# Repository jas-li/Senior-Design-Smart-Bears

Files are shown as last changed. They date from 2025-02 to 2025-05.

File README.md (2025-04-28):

# Senior-Design-Smart-Bears

### Team 29 - Smart Bears
Shamir Legaspi\
David Li\
Jason Li\
Lukas Chin\
Jake Lee

## Smart System for the Visually Impaired

Smart_System

## Objective

The goal of the Smart System for Visually Impaired is to improve its users’ abilities to navigate safely. 

The first way it achieves this goal is by providing users with more visual context about their surroundings through other mediums. Visual context is transformed into text descriptions in audio and semantic haptic feedback. 

A binary assessment of whether the current surroundings are navigationally safe or unsafe is quickly transmitted to the user through haptic feedback. This way, users can quickly make a decision to not proceed before knowing the full description of their surroundings which would take much longer to propagate than a simple buzzing signal. 

The system also illuminates the user’s wrist in dark light conditions. Though this does not directly help the user navigate, it helps others navigate around the user. 

In its current state, the system achieves all of these goals, but its performance in terms of latency, accuracy, and over helpfulness can always be improved. Each aspect of the system comes with a few things to keep in mind while developing them.

## Overview
* Stereo vision-based depth mapping and object recognition
* Real-time haptic (vibration) and auditory (speech) feedback
* One-button user interface on wrist-wearable
* Intelligent visibility system (LEDs for low-light)
* Wireless connectivity (WiFi and Bluetooth)
* Designed for expandability and compliance with accessibility and safety standards

## Quick Start

### Hardware Setup
1. Mount Cameras:
Attach the dual USB stereo cameras to the Smart Cap and connect to the Raspberry Pi’s USB ports.

2. Raspberry Pi:
Place the Raspberry Pi 5 in a weather-protected case. Power it with a 5V portable battery.

3. Wrist-Wearable:
Secure the wrist module to the user’s wrist, ensuring the photoresistor is unobstructed and the button is accessible.

4. Networking:
Connect both the ESP32 (in the wrist-wearable) and the Raspberry Pi to the same WiFi network.

5. Audio Output:
Pair the bone conduction headset to the Raspberry Pi via Bluetooth.

### Software Setup
1. Access Raspberry Pi:
SSH into the Pi or use a monitor and keyboard.

2. Project Directory:
Navigate to the project root directory.

3. Run Main Script:
Execute pi.py to start the main pipeline (waits for wrist-wearable trigger, handles image capture, depth mapping, LLM query, and feedback).

4. ESP32 Firmware:
Ensure the ESP32 is flashed with the provided firmware and has open UDP ports.
Run esp.py to handle communication for the buzzer and LEDs.

5. System Test:
Press the wrist-wearable button to initiate a query.
Confirm system activation by checking for audio (speech) and haptic (vibration) feedback.
### Operation
* Normal Use:
The user points their head, presses the wrist button, and receives a spoken description of the environment plus haptic alerts for nearby obstacles. LEDs activate in low-light conditions.
* Troubleshooting:
If feedback is missing, check WiFi/Bluetooth connections.
Restart ESP32 or Raspberry Pi if communication is lost.
For persistent issues, review setup logs and ensure all scripts are running.
### System Architecture
* Smart Cap:
Dual 2MP USB cameras, Raspberry Pi 5 (16GB RAM), portable battery, wireless connectivity.
* Wrist-Wearable:
ESP32 microcontroller, vibration motor, button, LEDs, photoresistor, adjustable strap.
* Audio Output:
Bone conduction Bluetooth headset.
* Communication:
UDP over WiFi (ESP32 ↔ Raspberry Pi)
Bluetooth audio (Raspberry Pi ↔ headset)

## Network
- We are currently using a router to connect to the Raspberry Pi 5 and the TinyPICO ESP 32.
  - SSID: `smartbears`
  - Password: ` `

## Raspberry Pi

We utilized a combiantion of SSH + RealVNC Viewer for faster development. To do so connect to the Pi at `192.168.1.141`
- user: `pi`
- password: `smartbears`

### Bluetooth

We have set up a bluetooth device to enable speaker output to the wireless headset.

To set up bluetooth with the Raspberry Pi, run `sudo bluetoothctl` to start the bluetooth control tool.

Find your device and its respective address. Then, pair and trust the bluetooth device:

```
pair 41:42:D4:02:07:00
trust 41:42:D4:02:07:00
```

You can now exit bluetoothctl with `exit`. You only need to do this once.

Run this command any time you want to reconnect the headset:
```
bluetoothctl connect 41:42:D4:02:07:00
```

## Final Hardware Diagram
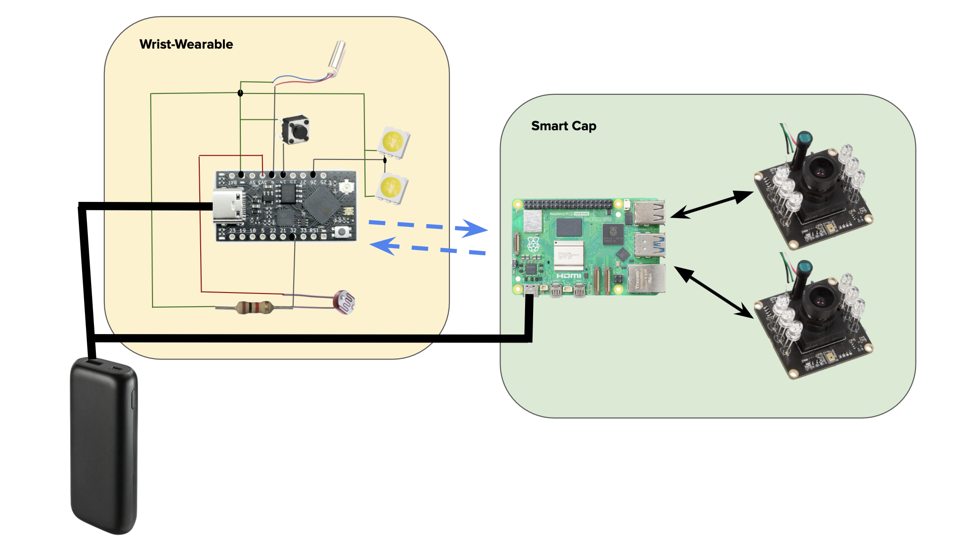
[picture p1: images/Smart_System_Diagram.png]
Smart System Diagram


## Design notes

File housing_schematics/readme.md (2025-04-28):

# CAD Files

CAD files used for designing the Smart System are located here.

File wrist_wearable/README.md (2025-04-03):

# Wrist-Wearable

MAC Address: D4:D4:DA:AA:31:E6

GPIO Pins Used
* LED 26
* Buzzer 4
* Button 14
* 32 Photoresistor

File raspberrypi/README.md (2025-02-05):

# Raspberry Pi Zero

### Router

**Plug the router into LAN2**

After turning on the router, the Raspberry Pi Zero should connect to the `smartbears` SSID. This may take 5-10 minutes. 

To check all devices on the network, connect to the wifi on your device, and go to the following link: http://192.168.1.1/status-devices.asp

### SSH

To ssh into the Raspberry Pi Zero:

```
ssh pi@192.168.1.142
```

You may get this error:

```
@@@@@@@@@@@@@@@@@@@@@@@@@@@@@@@@@@@@@@@@@@@@@@@@@@@@@@@@@@@
@    WARNING: REMOTE HOST IDENTIFICATION HAS CHANGED!     @
@@@@@@@@@@@@@@@@@@@@@@@@@@@@@@@@@@@@@@@@@@@@@@@@@@@@@@@@@@@
IT IS POSSIBLE THAT SOMEONE IS DOING SOMETHING NASTY!
Someone could be eavesdropping on you right now (man-in-the-middle attack)!
It is also possible that a host key has just been changed.
```

If so, try running:

```
ssh-keygen -R 192.168.1.142
```

Then, try to ssh into the pi again.

### PiCam

After running `picam.py`, you should be able to see the live feed from the PiCam at: http://192.168.1.142:5000/video_feed

### Video Stream Communcation 

Run `camera_stream_client` on the raspberry Pi

Run `camera_stream_server` on your computer

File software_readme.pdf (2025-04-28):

## Software Report

### smart_cap/stereoscopic/capture_calibration.py

This module handles capturing images for calibrating the stereoscopic camera setup. The only necessary inputs for this module are the camera feeds from both cameras. It is set up to work with two 1920 by 1080 USB cameras. Based on how the cameras are plugged in, they will be mapped to device number 2 for the left camera and device number 0 for the right camera. These parameters are the only things that should be subject to change if the cameras and their connection scheme are changed. The module saves the captured images to directories called left and right. When capturing calibration images for a new stereo camera setup, it is necessary to empty the contents of output directories first. It may be helpful to empty the output directories even when using the same camera set up in the event that an undesirable calibration error is obtained. It can also be useful to capture additional images without overwriting those in the output directories. This can be done by changing the image_count variable to a number higher than the greatest number in the output directory. To operate the script, both cameras must be plugged in. When the script is running, it will show a live feed of the camera outputs. To generate the calibration images, all one needs to do is place the calibration reference image in the frames of both cameras and press c to capture images. When a sufficient number of images are captured, q can be pressed to quit out of the script.

### smart_cap/stereoscopic/calibration.py

This module performs stereoscopic camera calibration given a calibration data set of images captured of a 10 by 7 checkerboard pattern of 25 millimeter squares. It then performs stereoscopic calibration by identifying the checkerboard pattern in each pair of images from the left and right cameras and finding the disparities between common points. This is then saved to a file called stereo_calibration.npz which can be renamed and referenced in the future.

### smart_cap/pi.py

This module runs all the code needed for our Raspberry Pi. It first opens up a UDP server to allow for communication with the ESP32. It then starts initialization of the cameras, text-to-speech module, and our cloud-based LLM. The camera initialization includes the calibration matrix obtained from the calibration modules. For our LLM initialization, we created a prompt to feed our LLM. Next, the code waits for a response from the UDP server, which will be a button press from the wrist-wearable. This will start up the whole Raspberry Pi process, which includes capturing an image using the two cameras, mapping it with conversion based on the calibration settings, and running the Gemini LLM. Our LLM inputs include the calibrated images and API key, and our output is text response, as well as a boolean ‘SAFE’ or UNSAFE’.

This boolean is sent to the ESP32 through the UDP server, and the text response is sent to the headset’s speakers through a text-to-speech module.

### wrist_wearable/esp.py

This module implements all core functionality for a wrist-wearable device using an ESP32 microcontroller. It establishes a WiFi connection to a specified network and communicates with a UDP server to send and receive real-time messages. The device continuously monitors ambient light using a photoresistor, dynamically adjusting the brightness of an onboard LED with a smooth, sine-wave gradient when low light conditions are detected. This ensures the device remains visible and responsive to changes in the surrounding environment.
User interaction is facilitated through a physical button. When the button is pressed, the module sends a notification to the server and awaits a response. Depending on the server’s reply, the device activates a vibration motor to provide haptic feedback: a single pulse for standard acknowledgments or a series of strong pulses for unsafe or emergency alerts. The ESP grabs either a ‘SAFE’ or ‘UNSAFE’ input from the Raspberry Pi which determines the vibration motor’s strength. The module is designed with efficient state management to avoid repeated signals and ensures all subsystems-light sensing, button detection, vibration feedback, and network communication-operate concurrently and responsively within the main loop. This makes the module suitable for applications where immediate feedback and environmental awareness are critical, such as personal safety or alert systems.

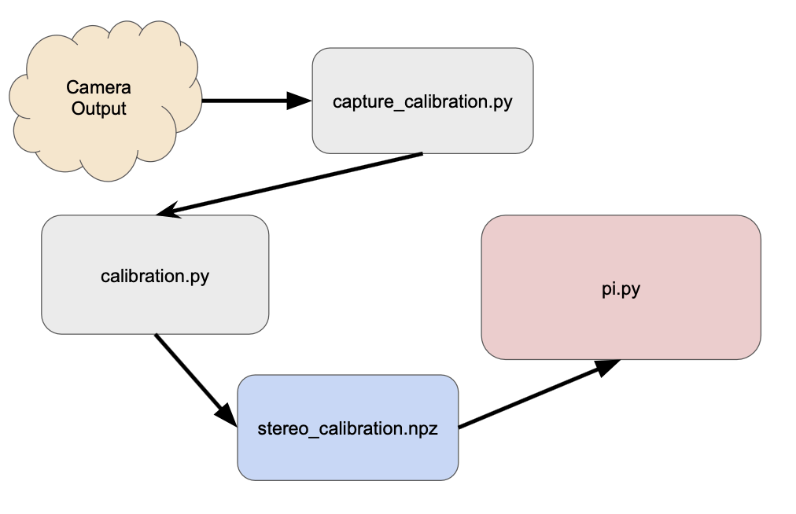
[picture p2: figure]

Flow chart indicating dependencies between functions, programs, and hardware outputs. Initially the cameras output multiple photographs that are used for calibration. capture_calibration.py handles all of the photographs that are taken and organizes them into two separate buckets, one for the left camera and one for the right camera. For optimal calibration, we recommend taking 20 photos on each camera; the capture_calibration.py script handles capturing photos for both cameras at the same time. Be sure to hold still when taking photos as there is a small delay in between taking the left and right camera photo. Photos taken with the capture_calibration.py should be of chessboard black and white patterns. See image below for reference. The chessboard image can be printed or displayed using a tablet. Multiple angles of the chessboard should be taken.

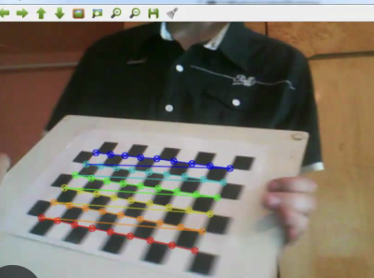
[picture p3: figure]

Once all of the photos are taken, calibration.py will then begin by detecting chessboard patterns in the image pairs. The script uses OpenCV’s findChessboardCorners to refine the black and white intersections in both left and right camera images. For each successful detection, it refines the corner coordinates with sub-pixel accuracy using cornerSubPix, then it stores the 3D object points (real-world chessboard coordinates) and 2D image points from both cameras. Individual camera calibration follows, where calibrateCamera calculates each camera’s intrinsic parameters:
- Camera matrix (focal length and optical center)
- Distortion coefficients (radial and tangential distortion)
- RMS reprojection error (lower values and indicate better calibration) The stereo calibration phase (stereoCalibrate) then determines the spatial relationship between cameras by solving for:
- Rotation matrix (R) and translation vector (T) between cameras
- Essential matrix and fundamental matrix for epipolar geometry
- Refined camera matrices accounting for stereo alignment
Finally, all calibration parameters get saved to stereo_calibration.npz for use in downstream applications like depth mapping. The script outputs RMS errors at each stage, with typical successful calibrations achieving errors below 0.5 pixels.

### Dev/Build Tool Information

The Raspberry Pi is running Python 3.11.2. No other build tools or languages are used. The core libraries and their versions are as follows.

google-genai==1.9.0
Pillow==9.4.0
opencv-python==4.11.0.86
pyttsx3==2.98
numpy==1.24.2
python-dotenv==0.21.0

The TinyPICO ESP32 is running MicroPython v1.24.1. Only libraries from the standard library are used, and no other build tools or languages are used.

### Installation Guide

The TinyPICO ESP32 comes with the appropriate MicroPython version installed. Since no other libraries are required, the project can be considered fully installed and functional once the GitHub repository is cloned. If another MicroPython-compatible device were to be used in future iterations instead of the TinyPICO ESP32, then that would be the only other dependency that would need to be installed. This can be done easily using Thonny IDE.
The Raspberry Pi does not have many dependencies to install. First, you must install Python 3.11.2. With Python installed, a developer can create a virtual environment and install the dependencies by running the following: pip install -r requirements.txt. Lastly, a .env file must be created with the contents GOOGLE_API_KEY=..., replacing the ellipses with the actual contents of a valid Google AI Studio API key. API keys can be generated from Google Studio at the following link: https://aistudio.google.com/app/apikey. The rate limits for free users are generous enough to serve developers.

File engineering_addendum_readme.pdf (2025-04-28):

## Engineering Addendum

### Goals and Progress

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

### Stereoscopic Setup

The stereo vision system is the backbone of this project. At times, getting both cameras to work simultaneously can be tricky. This task poses both software and hardware challenges. During development, cameras are often put in more vulnerable positions considering that housing may be improved or the cameras themselves are being swapped in and out. Because of this, it is important to always verify that the hardware is working, before trying to solve any potential software issues. Cameras can be verified individually, by plugging in one at a time and capturing an image. When connecting or removing devices from the Raspberry Pi, always make sure to power the Raspberry Pi off first. This prevents any potential damage to the devices. Once the cameras are verified to be working, it is also important to verify that the connection ports are working. These can be verified by plugging in a known working camera into an unverified port and taking a picture. Once the cameras and ports are verified, any issues with the stereoscopic setup can be attributed to software.
Another potential problem that may arise when working with the stereoscopic setup is the device numbers used to reference the cameras. On many setups like with a laptop, when two cameras are plugged in, they can be referenced through device numbers 0 and 1. However, in our experience with the Raspberry Pi, the device numbers were not always consecutive and in order, leading us to use reference numbers 0 and 2. These references are determined by the underlying operating system, so even if a different library is used to interact with the cameras, this referencing guide will remain relevant. An example of establishing the video capture references to the cameras can be found below.

# Example of initializing video captures

cap_left = cv2.VideoCapture(0) # Adjust index if needed cap_right = cv2.VideoCapture(2) # Adjust index if needed

### Stereoscopic Calibration

When iterating on the camera selection or the mounting system, it is important to always calibrate the cameras and their stereoscopic setup. Optimizing the calibration error is pivotal for ensuring that the depth mapping output is accurate and useful. Our calibration scripts use a checkerboard pattern with 10 by 7 internal corners as the reference calibration image. Each of the squares of the checkerboard When using the calibration scripts, make sure to only settle for a calibration error below 1 pixel. Ideally, the mean error should be below .5 pixels. Any higher mean error will not yield a helpful result. To improve this calibration error, make sure to take the calibration images in well-lit conditions. It is important to also have the calibration reference image fully in frame and in multiple different angles across all of the captured calibration images.

### Depth Mapping

Even after performing calibration, there are many parameters to tune that can affect the quality and usability of the depth map. The main things we modified when working with OpenCV’s stereo block matching algorithm for depth mapping were the parameters for the number of disparities and the block size. Other features we modified were the speckle window size, speckle range, and texture threshold. The reason we modified these aspects was to find a balance between making the depth mapping sensitive enough for low texture objects without having a large, distracting amount of noise.

### Working on the ESP32

The ESP32 deals with many hard coded constants. These range from WiFi credentials and the IP of the Raspberry Pi to the GPIO pins and parameters involved with sensors and output. When iterating on the ESP32 code, it is important to ensure that the constants used in the code reflect what is mapped out in the hardware. It is important to make use of the TinyPICO pin map for this. Ensuring that devices that require PWM or ADC are plugged into the appropriate ports is pivotal to the success of the project. Though the code handled by the ESP32 and the wrist wearable is not required to be concurrent, it would be best to avoid long sequential blocks of code that would prevent other functions from updating, when iterating on the functionality of the wrist wearable.

### Prompt Engineering

Though it is good to save on tokens when using LLMs, we found that including more tokens in the prompt can be beneficial in many cases. A longer prompt that does not increase the requirements of the output can improve the specificity of the train of thought of the LLM and its concision. Often, the bulk of the latency when interacting with an LLM comes from the LLM producing its output. By reducing the length of the output by having specific constraints in the prompt, latency can be reduced. Especially since we are passing images to the LLM alongside the text, the extra tokens in the text portion of the prompt are well worth the savings on output tokens.

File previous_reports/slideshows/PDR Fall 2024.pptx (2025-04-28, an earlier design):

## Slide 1

Smart System for Visually Impaired

Smart System for Visually Impaired

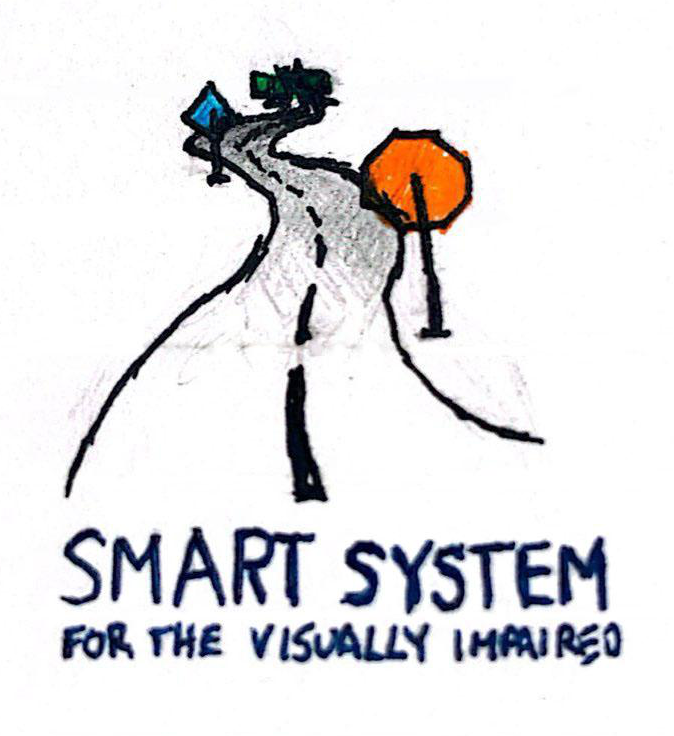
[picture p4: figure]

Lukas Chin, Jake Lee, Shamir Legaspi, David Li, Jason Li

## Introduction

## Introduction

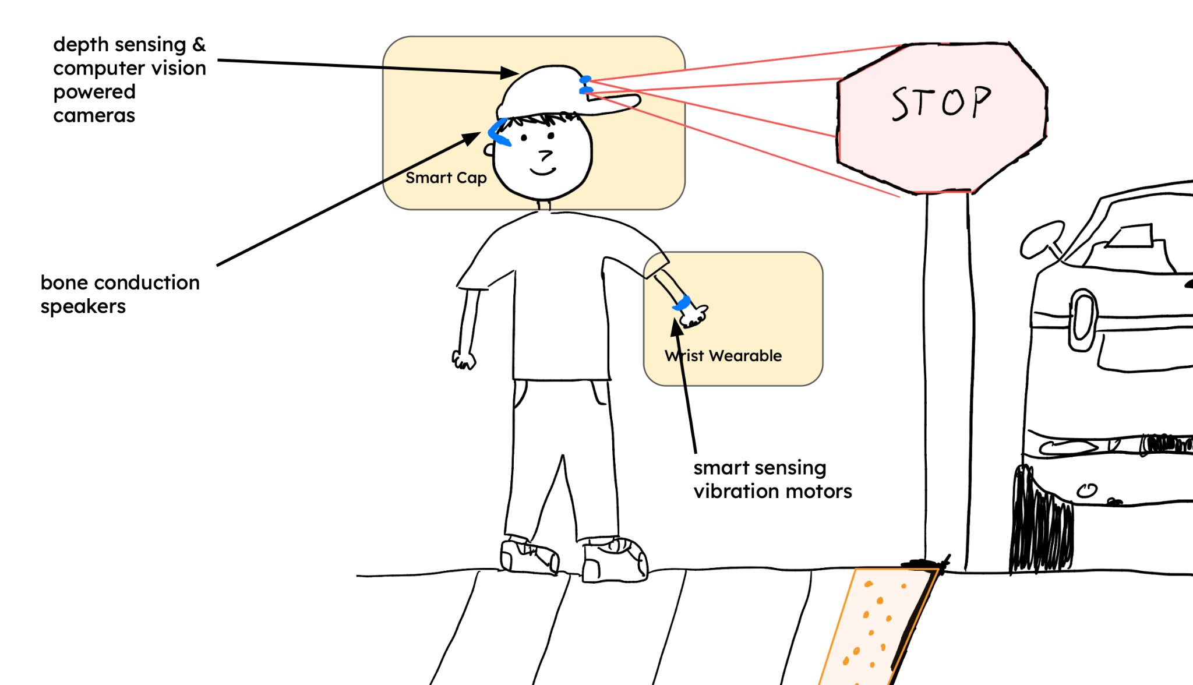
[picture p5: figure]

## Problem Statement

## Problem Statement

• Visually impaired individuals benefit from navigational assistance.
• White canes and guide dogs have significant limitations.
• Current solutions inadequately translate environmental information.
• Society requires accessible solutions.

## Requirements

## Requirements/Deliverables

Required Functions
• Transmit haptic signals through vibration motors
• Stream and process video inputs
• Text-to-speech output
• Real-time feedback (<1s)
• Lightweight and comfortable for extended wear (<1lb)
• Battery life: 12+ hours per charge
• Easy to use with minimal training required
• Multi-environment operation (<10% accuracy difference between different environments e.g. indoors and outdoors)

Deliverables
• Wrist wearable that transmits differentiable haptic signals based on surroundings.
• Smart cap that gives an audio description of surroundings based on objects detected, object distances, and user queries.

## Block Diagram

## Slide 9

Smart System for Visually Impaired

Smart Cap

Raspberry Pi 5

Raspberry Pi Camera Module

Raspberry Pi Camera Module

Microphone

Human speech input

Feeding live video stream

Depth Map Processing

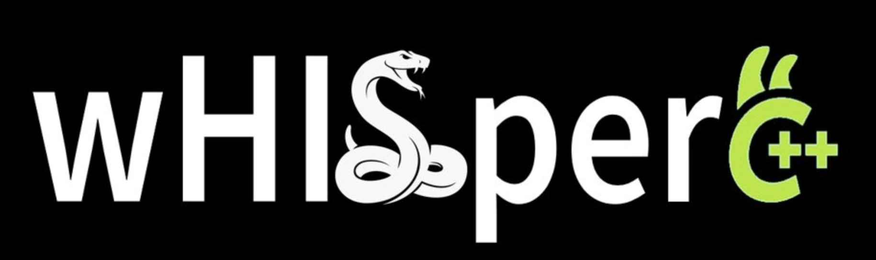
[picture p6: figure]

Bone conduction speakers

Object Inquiry Assistant

Text-to-Speech

Wrist Wearable

ESP32 Microcontroller

Intelligent Visibility System

Photoresistor

Light Emitting Diode Array

Variable Vibration Motors

## Technology/Design

## Object Detection

Object Detection Model: Implemented YOLOv3, pre-trained on the COCO dataset, via the OpenCV library to recognize common objects.
Hardware Setup: Utilized a Raspberry Pi Zero W with a Pi Camera Module to capture video streams, transmitted to an OpenCV server over a TCP connection for processing.
System Functionality: The server performs object detection on the video stream and integrates a text-to-speech library (pyttsx3) to announce identified objects in the frame.

## Depth Mapping and Distance Calculation

- Utilizing 2 Raspberry Pi camera modules, the Smart Cap can accurate sense depth of field.
- Depth Mapping can be to calculate distance of nearby and far obstacles for everyday walking.
- Smart Cap can provide haptic feedback even more reliably to the user with 2 Raspberry Pi camera inputs versus 1 camera (no depth mapping).

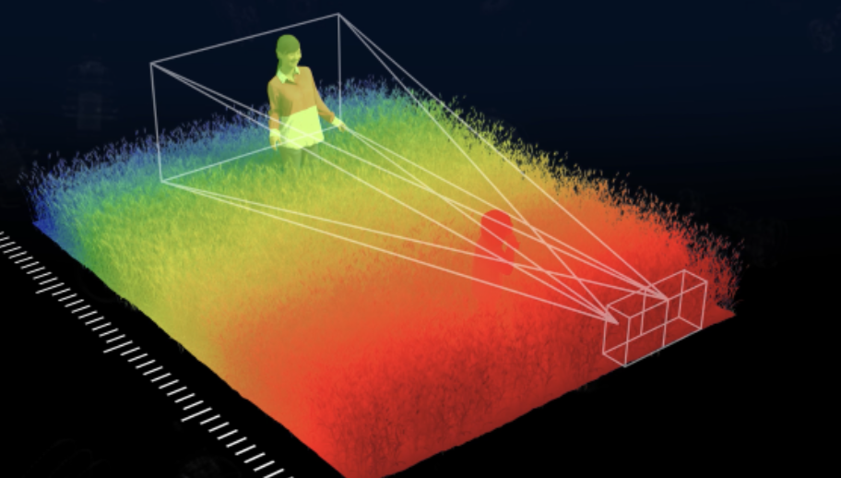
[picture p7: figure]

## Whisper.cpp

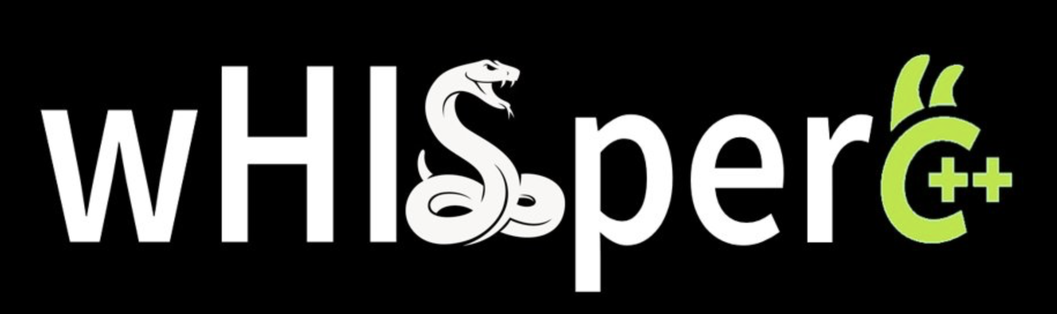
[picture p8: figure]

- Through a microphone on the Smart Cap, users can record a query that is processed into a format consumable by Whisper.cpp.
- The Smart Cap can then run the Whisper.cpp process with the audio of the recorded query as input to output text.
- Through this speech-to-text system, users will be able to speak to make queries that are turned into text that modifies the output of the Object Inquiry Assistant.

## Object Inquiry Assistant

Inputs:
- Depth map processing and OpenCV information from Pi Camera live-stream
- User speech-to-text from microphone using whisper.cpp
Outputs:
- Text-to-speech into bone conduction speakers
- Vibration motors on the wrist wearable

## Wrist Wearable

Inputs:
- Wireless data stream from Smart Cap visual feedback
- Outdoor illumination detection from photoresistor
Outputs:
- Variable vibration motors for haptic feedback and user notification
- High-visibility LED for user safety and convenience

## Prototype Results

## Prototype Results

Tasks | Successful? (Y/N)
Raspberry Pi and TinyPico are connected to router’s network | Y
Raspberry Pi’s camera module’s live stream can be observed on user’s computer | Y
TinyPico successfully sends request and receives responses | Y
TinyPico’s received responses trigger “notifications” which prompt vibration motors to turn on | Y
Computer vision Python script through user’s computer’s webcam successfully detects objects and reports accuracy of detection | Y
Able to communicate audibly to the user the detected objects | Y
User is able to sense a vibration when a target object is in frame | Y
User feedback in under 1 second | N

## Schedule

## Gantt Chart

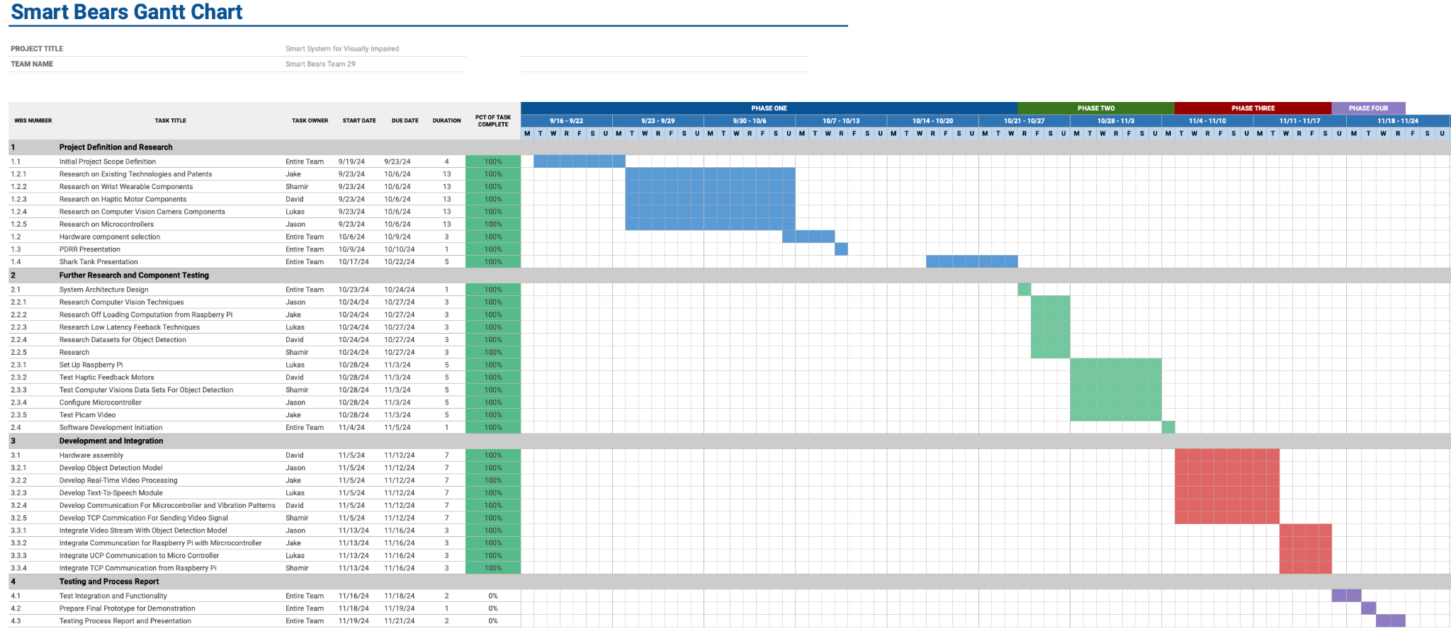
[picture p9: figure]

## What’s Next?

- Hardware Optimization: Design and develop lightweight, ergonomic housing design for our system’s wrist-wearable and smart cap
- Communication Enhancement: Optimize Raspberry Pi and microcontroller integration
- Real-Time Performance: Enhance feedback mechanisms
  - Improve livestream quality and reduce delay
  - Optimize alert delivery system
  - Implement more responsive user notifications

## Thank You! + Questions?

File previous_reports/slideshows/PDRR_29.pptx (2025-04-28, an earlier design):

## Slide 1

Smart System for Visually Impaired

Alan Pisano

29

Problem Statement

- People with visual impairments cannot always navigate the world around them unassisted.
  - Obstructions and imperfections can be dangerous.
- Current solutions may be difficult to use or maintain.
  - White canes are not hands free and require hand mobility.
  - Guide dogs must be taken care of and can be expensive.
- Current solutions are limited in their ability to translate the world into something consumable for people with visual impairments.
  - A lot of navigational information is lost or not consumed at all by white canes or current wearable devices.
- Accessibility is important to our society.

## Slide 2

Smart System for Visually Impaired

Alan Pisano

29

Visualizations

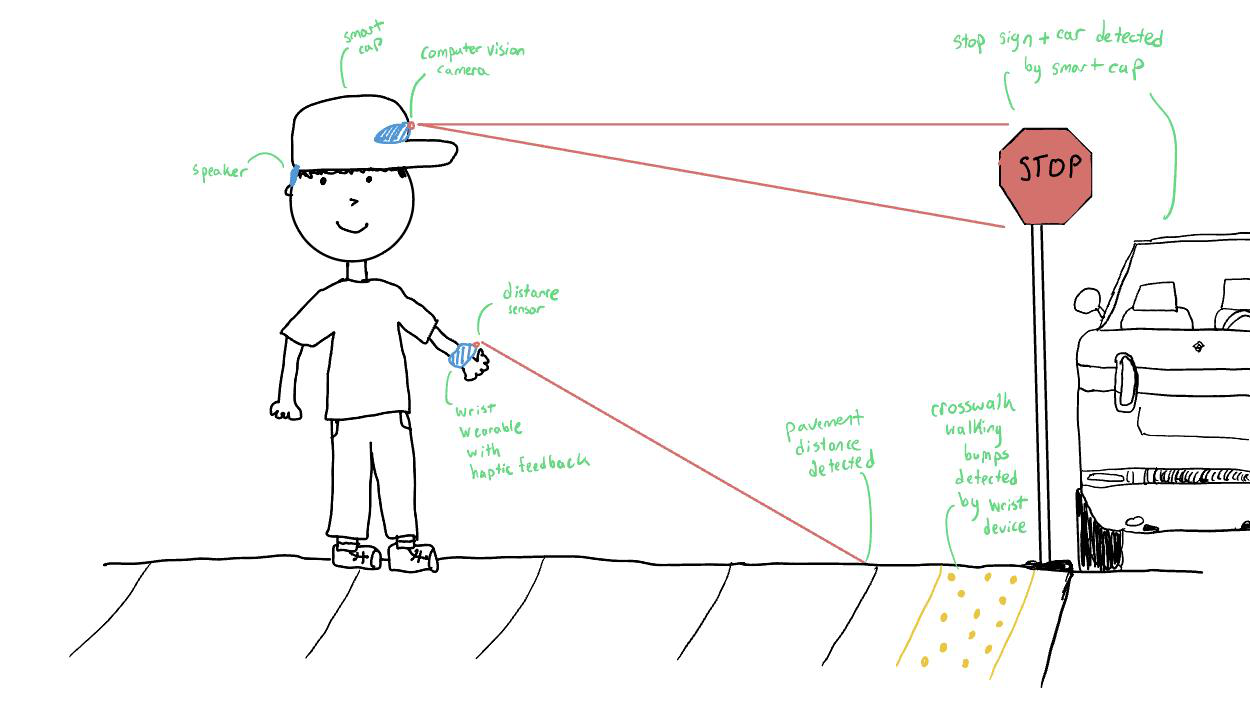
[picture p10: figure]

smart cap

computer vision camera

stop sign + car detected

speaker

distance sensor

wrist-wearable

pavement distance detected

crosswalk bumps detected

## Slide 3

Smart System for Visually Impaired

Alan Pisano

29

Deliverables

Our end deliverable includes a working prototype of a functional smart system that includes a pair of sensor-attached head and wrist wearable devices. The smart head and wrist wearable devices will utilize various feedback mechanisms to alert the user.
Our intermediate deliverables include a finalized list of sensors for both head and wrist devices and basic circuit visualization of the smart system.

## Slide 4

Smart System for Visually Impaired

Alan Pisano

29

Requirements

Functions
- Tactile Feedback: Deliver haptic signals to help users differentiate between various objects in the environment.
- Camera-based Vision: Integrate a camera into headwear that audibly communicates text from signs or books to the user through real-time speech output.
- Real-Time Feedback: Provide real-time responses (within 100 milliseconds) to object detection through auditory or tactile signals.

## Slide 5

Smart System for Visually Impaired

Alan Pisano

29

Requirements

Objectives
- Portability: The device should be lightweight and comfortable to wear for long periods.
- Low Power Consumption: The system should operate for at least 12 hours on a single charge.
- Ease of Use: The system must require minimal training for visually impaired individuals to operate effectively.
- Non-Intrusive Feedback: Feedback should be non-disruptive, such as subtle vibrations or tones, without overwhelming the user.
- Multi-environment Usability: The system should work effectively both indoors and outdoors, in different lighting and terrain conditions.

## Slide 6

Smart System for Visually Impaired

Alan Pisano

29

Requirements

Constraints
- Size and Weight: The device must not exceed 300 grams to ensure it is wearable and comfortable.
- Battery Life: The system must run on a battery with at least a 12-hour capacity.
- Durability: The device should withstand drops from 1.5 meters and be water-resistant to ensure usability in various weather conditions.
- Safety: The feedback mechanism (vibration or sound) must not pose any risk of injury or discomfort to the user.

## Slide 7

Smart System for Visually Impaired

Alan Pisano

29

Competing Technologies / Patents / Other Products
- AiSee
  - Description: Wearable device with AI-powered camera, bone conduction audio, and Q&A capabilities
  - Limitations: Not commercially available, Short battery life, Long processing times
- OrCam
  - Description: Wearable camera that attaches to glasses, provides audio descriptions of surroundings
  - Limitations: Short battery life, Connectivity issues, Struggles in low light conditions
- BuzzClip
  - Description: Small wearable that uses ultrasound to detect obstacles and provides haptic feedback
  - Limitations: Limited range, Not resistant, requires the use of cane or guide dog

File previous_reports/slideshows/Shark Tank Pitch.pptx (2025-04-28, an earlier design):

## Smart System for Visually Impaired Smart System for Visually Impaired

Experience the World


## Value Proposition: Our Users 🧑🏻‍🦯‍➡️

For people with visual impairments 😎
Who want to better understand and navigate their environment independently, beyond the limited information provided by traditional aids. 🦻

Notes: Note that sometimes you need more than one value proposition. For example if the beneficiary does not pay you, then you need one value proposition for your beneficiary and one for your paying customer.

## Value Proposition: Our Product 🧢 ⌚

The Smart System for the Visually Impaired is a dual-component wearable technology (smart cap and wrist device). 🤖
That provides comprehensive environmental awareness through real-time multimodal feedback, transforming visual information into consumable audio and haptic signals. ⛰️

## Value Proposition: Our Advantages 📈

Unlike existing wearable assistive devices that focus on single-mode feedback or have limited environmental detection capabilities, 🦯
Our product creates a more complete understanding of the surroundings through an integrated dual-device approach that combines
- computer vision
- distance sensing
- intuitive multimodal feedback systems
to translate the visual world into easily consumable information about objects, text, faces, and obstacles at all heights. 🦮

## Our Design

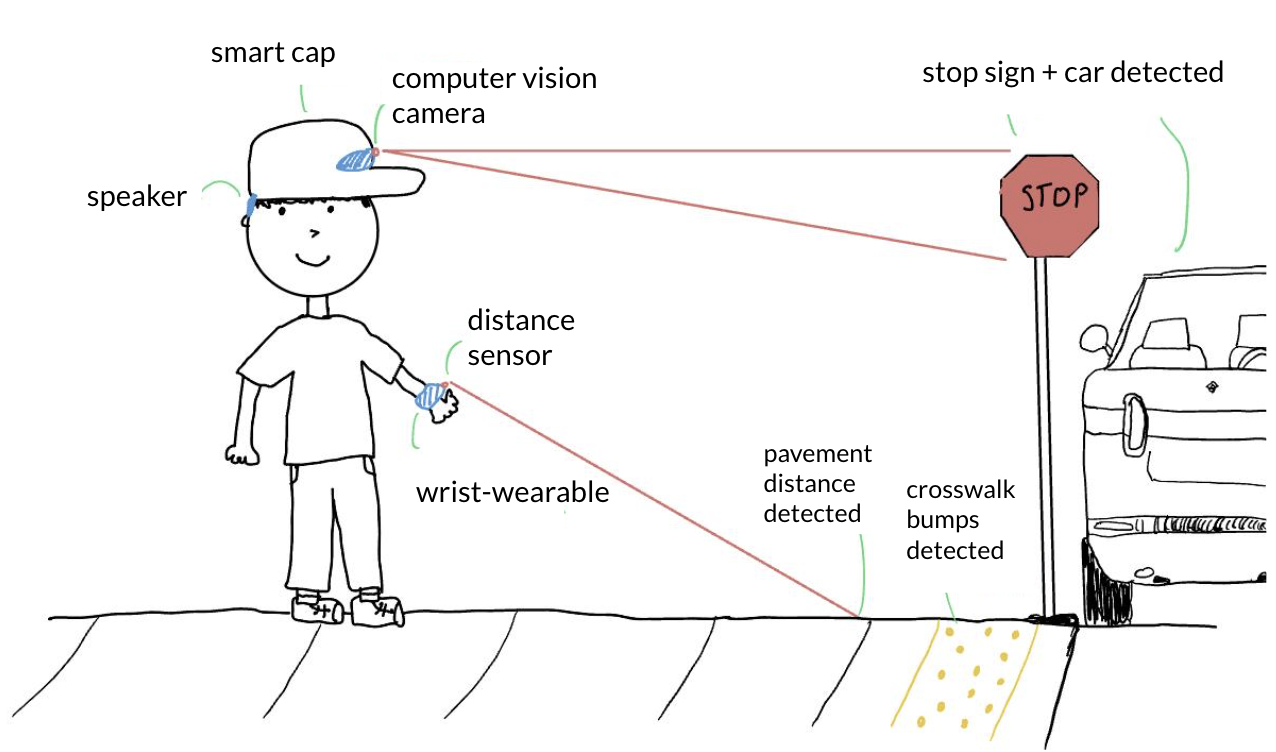
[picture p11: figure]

## Our Design

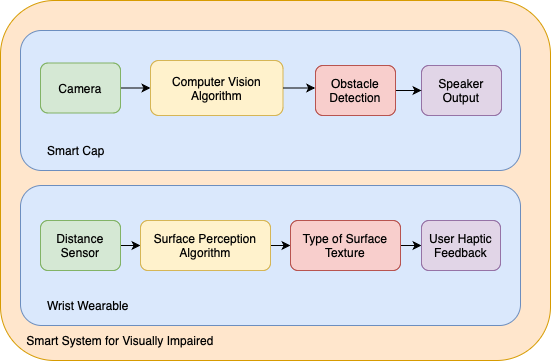
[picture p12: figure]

## M V P

- Accurate environmental sensing
- Mimicking of white cane functionality
- Precise user haptic and auditory feedback
- Ergonomic and simple to use

Smart System for Visually Impaired Pair system of wrist-wearable and smart cap for visually impaired individuals designed to aid navigation through impressive environment sensing and precise haptic and auditory feedback. The Smart System empowers over 7 million visually impaired Americans with enhanced independence and safety, improving their social and professional opportunities through accessible, hands-free navigation technology.

Special Sauce
- Real-time haptic sensory feedback through wrist-worn device to mimic white canes
- Leverages computer vision for environmental awareness and object recognition
- AI-powered voice assistant that allows users to verbally inquire about their surroundings

Technology Solution
- Smart Cap with AI-powered vision
- Wrist-worn haptic navigation device
- Voice-activated environmental assistant

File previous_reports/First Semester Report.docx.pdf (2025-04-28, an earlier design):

## Boston University Electrical & Computer Engineering

EC463 Senior Design Project

## First Semester Report

## Smart System for Visually Impaired

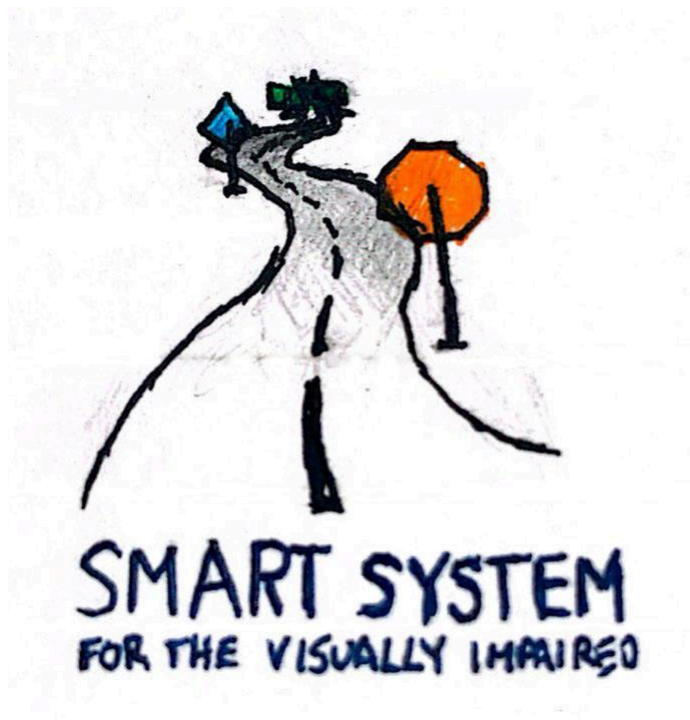
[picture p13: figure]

Submitted to

Michael Hirsch
mhirsch@bu.edu
8 Saint Mary's Street, Boston, MA 02215

by

Team 29
Smart Bears

Team Members

Lukas Chin | lchin10@bu.edu
Jake T. Lee | jaketlee@bu.edu
Shamir L. Legaspi | slegaspi@bu.edu
David Li | dav@bu.edu
Jason Li | jli3469@bu.edu

Submitted: 12/09/2024

First Semester Report | 2

Table of Contents

Executive Summary | 2
1.0 | Introduction | 3
2.0 | Concept Development | 5
3.0 | System Description | 8
4.0 | First Semester Progress | 10
5.0 | Technical Plan | 13
6.0 | Budget Estimate | 17
7.0 | Attachments | 18
7.1 | Appendix 1 – Engineering Requirements | 18
7.2 | Appendix 2 – Gantt Chart | 19
7.3 | Appendix 3 – Technical References | 20
7.4 | Appendix 4 – Drawing and Schematics | 21

(right click on Table of Contents to update fields and page numbers automatically)

Executive Summary
Smart System for Visually Impaired
Team 29 - Smart Bears

In the United States, there are over 20 million people who are visually impaired, with about 1 million of those with blindness. Every day these visually impaired individuals have trouble navigating their surroundings with many needing to use white canes or guide dogs for assistance. While white canes and guide dogs provide great aid for everyday navigation, our Smart System for Visually Impaired offers even greater enhanced mobility through wearable technology that combines obstacle detection, real-time object recognition, live haptic and auditory feedback, and speech control. Smart System for Visually Impaired uses cutting edge computer vision techniques to detect everyday hazards, and it listens to the user for quick and automatic speech input. Our Smart System for Visually Impaired combines a Smart Cap and an Intelligent Wrist-Wearable wirelessly to provide the user with exceptional environmental awareness and navigation confidence.

Team 29 Smart Bears

### 1.0 Introduction

The visually impaired face significant challenges in navigating both indoor and

outdoor environments, particularly in unfamiliar settings. These mobility challenges

primarily involve avoiding obstacles, detecting ground level changes, and navigating

street crossings. Despite having traditional aids like white canes and guide dogs, many

visually impaired individuals still lack adequate accessibility to easily navigate

independently. A guide dog comes with significant ongoing expenses, including

specialized food that can cost up to $150 monthly, regular veterinary care, grooming

services, and unexpected medical expenses. Guide dogs also cannot serve indefinitely

and will eventually need to retire. They may also face unforeseen health issues that could

end their service prematurely. These limitations make it difficult to emotionally and

physically rely on guide dogs for independent transportation and navigation. White canes

on the other hand, while proven to be extremely effective in assisting visually impaired

people in navigating their surroundings, also create unsafe situations as they can get stuck

in sidewalk cracks and crevices, potentially harming the user. Additionally, they can not

detect vehicles or obstacles that are further than the cane’s reach.

We introduce, “Smart System for Visually Impaired” which aims to provide

another solution for visually impaired individuals to navigate their surroundings better,

and while the product is not designed to fully substitute current solutions, it strives to be a

supplement to give the user even greater control and confidence when commuting every

day. Our approach in creating “Smart System for Visually Impaired” is to create a

portable, smart, and easy to use device that combines numerous methods of user feedback

and environment detection to allow the visually impaired user to better navigate their surroundings. We introduce a Smart Cap device and a Wrist-Wearable device that act

together as a smart system pair. The Smart Cap combines computer vision techniques

with real-time object recognition to provide comprehensive environmental awareness

through relaying that information to the Wrist-Wearable device wirelessly. Both the

Smart Cap and Wrist-Wearable feature different ways to alert the user ranging from

haptic feedback vibration and speaker audio.

Smart System for Visually Impaired will address navigational challenges of

visually impaired individuals through this comprehensive multi-modal approach. The

system enhances environmental awareness through the Smart Cap object detection

capabilities as well as the Wrist-Wearable haptic feedback mechanisms. Unlike

traditional aids, our pair of smart devices offers dynamic, real-time environmental

detection while maintaining hands-free operation.

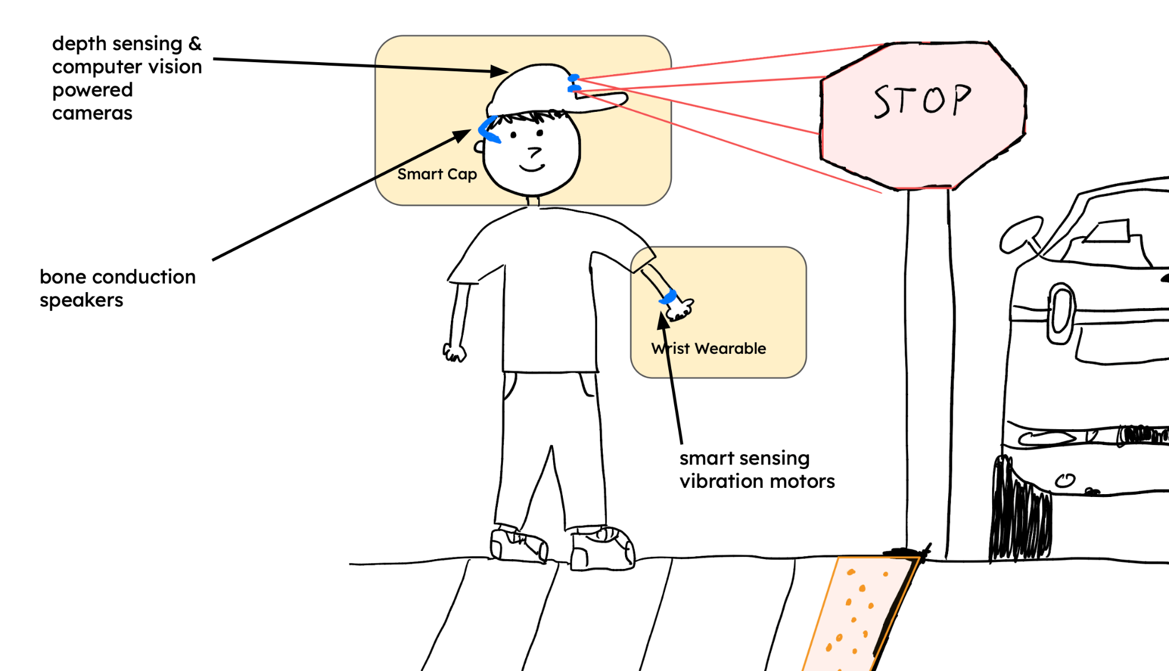
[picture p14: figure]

Fig 1. Mock-up of Smart System for Visually Impaired, showing Smart Cap and

Wrist-Wearable use case.

### 2.0 Concept Development

Based on our customer’s needs and requirements as concisely identified in

Appendix 1, we’ve carefully created an initial proposed concept to not only tackle

problems visually impaired individuals face but also tailor our design to fit within the

constraints and preferences of our customer. Our customer requested a solution that

would be hands-free, utilizes relevant object detection techniques, and is light and

portable to use. Given these constraints, we honed in on the hands-free aspect of the

design and as a group we ideated on creating a system that would replace a conventional

white cane. Our wrist-wearable device instead will act like a white cane, utilizing

numerous lidar and distance sensors to detect the ground below the visually impaired

user. The measurements from the sensors will then be read by the microcontroller on the

device and translated into haptic feedback for the user—essentially simulating a white

cane but without the need of a white cane. With this approach, we believe we could

revolutionize the way a visually impaired user interacts with their surroundings as now

they can benefit from the feedback of a white cane while being hands-free, allowing them

to gain greater independence on top of the improved confidence in navigation. This

system would also involve the smart cap’s multi-camera computer vision algorithm to

provide even more information for the user to navigate every day.

However, after much deliberation on the possibility of this smart system

combined with extensive feedback from Shark Tank, we had to go back to the drawing

board, as replicating white cane feedback via lidar/distance sensors proved to be a more

difficult task than first anticipated. The first realization is the polling rates of these

sensors would have to be tremendously high in order to pick on instantaneous movement

and changes to the ground below the user. The second realization is that the sensors would need a completely separate support sensor to aid in rotational movement of the

user’s wrist because with every wrist movement, the sensors would have to recalibrate to

adjust. Lastly, the lidar/distance sensors would have to be extremely accurate as well as

portable and energy efficient enough to be worn as a wrist-wearable device. All of these

circumstances led us to instead pivot from replacing the white cane to supplementing it.

In doing this, our ideas of haptic feedback through environmental awareness is still

maintained with the possibility of hands-free operation, but emphasis is placed on the

benefits of conjunctional use with a white cane.

Our newly iterated solution combines two key components: a smart cap and a

wrist wearable device. This dual-device approach addresses the problem through a visual

processing system and feedback mechanics.

In the smart cap, we implemented the YOLOv3 object detection model, a dual

Raspberry Pi camera setup, Whisper.cpp, and a feedback mechanism using bone

conduction speakers. The YOLOv3 model is used through OpenCV for real-time object

recognition, in which the user will be alerted when it sees signs, close objects, etc. We

decided on adding two cameras in our PiCam setup for more accurate depth mapping and

distance calculation. Whisper.cpp has speech-to-text capability, which allows for user

queries through voice commands. Finally, the bone conduction speakers will

communicate with the three visual processing systems and inform the user of the

recognized objects in front of him/her, as well as any output from their spoken user query.

We plan to implement two additional feedback mechanics in our wrist wearable

device: vibration motors and a high-visibility LED system. The vibration motors will be

an additional alert from the OpenCV data; when objects are too close to the user, the vibration motors will create a greater vibration. The LED system was added to our wrist

wearable to allow for the user’s safety.

### 3.0 System Description

We will provide a system with a smart cap and smart wrist wearable to increase

the navigational abilities and safety of visually impaired users. At a high level, the

product will consume visual information and transform it into audio and haptic signals

that can be interpreted by visually impaired users.

The smart cap will capture images of the area in front of users, identifying

navigational objects and obstacles with an 80% detection rate and a mapping to their

relative distances. Users will be notified of relevant detected objects through audio

signals transmitted through bone conduction speakers at 60-70 decibels, a range that is

audible without causing ear damage. Users will also be able to query the system through

speech to tailor what the system considers to be the most relevant objects. The

responsiveness of the system will vary based on whether the user makes a query or not.

Without a query, the system will have a response time such that a picture can be taken,

processed, and converted to audio output at least once per second. When responding to a

query, the response time will allow for pictures and audio to be captured, processed, and

converted to output at least once every four seconds (plus the duration of the query made)

to maintain conversational pace. The goal of providing users with descriptions of objects

in front of them is to allow them to make navigation decisions. Because of this, relevant

objects are defined as objects that help users make these decisions (stop signal at

crosswalk -> stop, go signal at crosswalk -> go, dead end -> turn). Relevant objects will

be detected at a rate of 65%.

The smart wrist wearable will augment the output of the smart cap, outputting

signals that suggest a navigational action based on the relevant object identified by the

cap. Given a relevant object and suggested action as input from the smart cap, the wrist wearable will be able to output distinct signals that reflect the suggested action within

100 milliseconds. The wrist wearable will also house an intelligent visibility system. It

will have an LED array capable of producing 50 lumens when a threshold is reached,

detected by the output of a photoresistor.

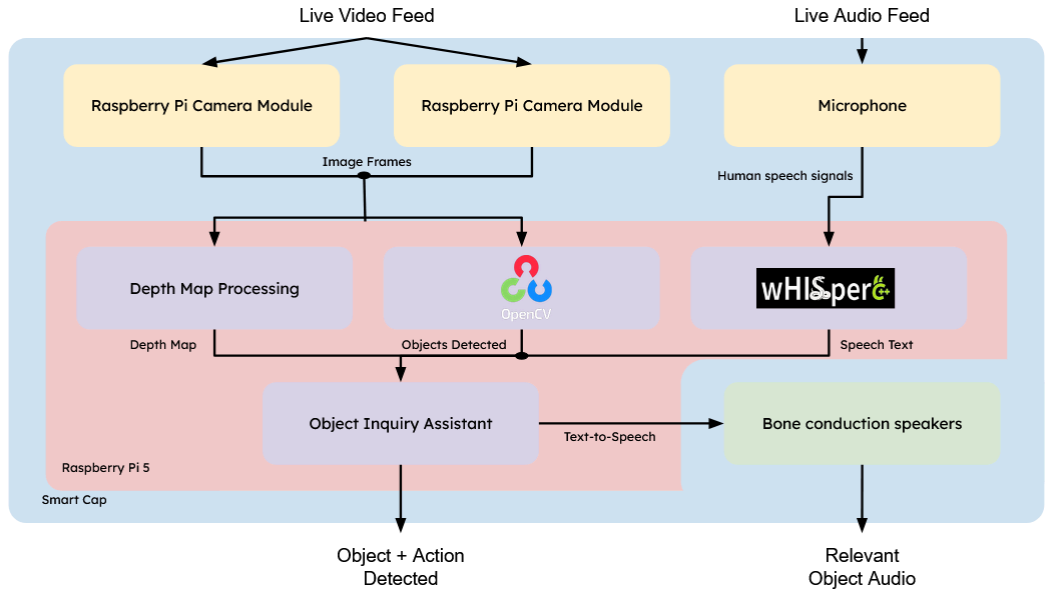
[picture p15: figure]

Fig 2. Block diagram of smart cap showcasing how video and audio are transformed into

audio to be consumed by the user and signals to be used by the smart cap.

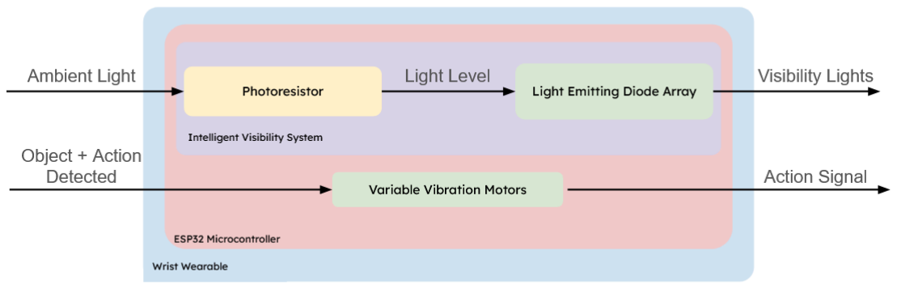
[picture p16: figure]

Fig 3. Block diagram of smart wrist wearable showcasing how light and detected objects

are transformed into outputs for the user.

### 4.0 First Semester Progress

This semester, our team focused on establishing a proof of concept for the “Smart

System for Visually Impaired.” We worked on integrating hardware components,

improving communication across devices, and refining our computer vision capabilities.

One key limitation we encountered was the lack of computing power in the Raspberry Pi

Zero W, which made it challenging to handle the computational demands of real-time

computer vision processing. To address this in the next phase, we plan to upgrade to a

Raspberry Pi 5 and add an additional camera module to enable stereo vision and depth

map calculations, enhancing the system's ability to detect obstacles and provide more

accurate feedback.

Despite the limitations of the Raspberry Pi Zero W, we successfully established

robust connections and communication between all our microcontrollers and auxiliary

devices. This achievement was crucial for ensuring smooth operation and feedback from

both the Smart Cap and the Wrist-Wearable device.

For the computer vision aspect, we found success with the YOLOv3 real-time

object detection model, training it on the COCO dataset to detect common objects. While

the model has shown promising results, we are continuing to fine-tune it to detect more

specific objects, such as road signage and text on the street. Although we have not fully

achieved this capability yet, our extensive research and testing have brought us closer to

the goal.

A significant challenge we faced was minimizing the latency in streaming video

from the Raspberry Pi Camera Module to our processing source. Initially, there was a

4-second delay in video streaming, which we aimed to reduce. In the prototype, we opted to keep the Raspberry Pi lightweight by using the Raspberry Pi Zero W solely for video

capture and streaming. The video feed was then sent to an external processing source,

such as our laptop, for object detection. While the latency was an issue, this setup

allowed us to evaluate our approach and consider improvements for future prototypes.

To ensure the accessibility of our product, we incorporated a text-to-speech

library that announces the objects detected by the OpenCV model, making the system

more intuitive for visually impaired users. This feature will be crucial as we continue to

refine the user experience in future iterations.

Below are the key results from our prototype testing:

- Hardware Communication and Integration:
- All microcontrollers (Raspberry Pi Zero W, TinyPico) successfully

established stable connections with the router and the server device.

- The Raspberry Pi Camera Module streamed video to the local computer

with minimal interruption.

- Computer Vision:
- The YOLOv3 model successfully detected common objects from the

COCO dataset with an accuracy of 80%.

- Preliminary research into fine-tuning the model for detecting road signage

and street text is ongoing.

- Latency and Streaming:
- Initially, there was a 4-second delay in video streaming from the

Raspberry Pi Camera Module to the laptop. Plans are in place to improve

this latency in the next prototype.

- Haptic Feedback:
- The system successfully activated the two distinct vibration motors (on/off

and varying intensity) based on proximity and obstacle detection.

- The vibration feedback patterns (triple pulse, gradual intensity increase,

and constant vibration) were tested, with users successfully differentiating

between them 90% of the time.

- Text-to-Speech Accessibility:
- Integrated a text-to-speech library to announce detected objects,

improving accessibility for visually impaired users.

Overall, the first semester was marked by significant progress in hardware

integration, communication, and computer vision research. Our next steps will focus on

enhancing computing capabilities, improving object detection, and reducing latency to

ensure a more responsive and efficient system for users.

### 5.0 Technical Plan

Task 1: Integration of Dual Pi Camera Modules

- Description: This task involves configuring and integrating two Raspberry Pi Camera Module v2 devices with the Raspberry Pi 5 to enable stereo vision. The cameras, each capable of 8MP resolution and 1080p video at 30 fps, will be connected to the Raspberry Pi 5 using CSI ports. The Raspberry Pi 5, powered by a Broadcom BCM2712 quad-core processor with 4GB RAM, will run Raspbian OS and utilize Python with OpenCV for camera interfacing. The process includes connecting the cameras, installing OpenCV, and configuring scripts for synchronized image capture. Testing will verify the synchronization, resolution, and frame rate performance, ensuring the cameras provide synchronized 1080p image streams.
- Deliverable: Both cameras connected and functioning, providing synchronized image capture.
- Lead: Jason
- Assisting: Jake

Task 2: Development of Stereo Vision Algorithm

- Description: This task focuses on implementing a stereo vision algorithm to compute depth maps from the dual camera setup. Using a Semi-Global Matching (SGM) or Block Matching algorithm implemented in Python with OpenCV, the system will produce depth maps with a resolution of at least 480×320 pixels and a processing time under 1 second per frame. The cameras will first undergo stereo calibration using OpenCV’s calibration functions, followed by implementing and testing the algorithm on stereo image datasets, such as Middlebury or KITTI. The depth map accuracy will be optimized to support precise navigation for visually impaired users.
- Deliverable: A functional depth mapping system capable of determining distances between detected objects and the user.

- Lead: Shamir
- Assisting: David

Task 3: Smart Cap Housing Design

- Description: This task involves designing and fabricating a durable and lightweight housing unit for the smart cap, which will securely hold the Raspberry Pi 5 and two Pi Camera Modules. The housing will be modeled using CAD software like SolidWorks, with specific provisions for securing the hardware and ensuring heat dissipation. The design will be fabricated using a 3D printer with PLA material and tested for durability, fit, and weather resistance. After installing the hardware in the housing, adjustments will be made based on real-world testing feedback to ensure ergonomic use.
- Deliverable: A durable, lightweight housing unit that meets ergonomic and safety standards.
- Lead: Jake
- Assisting: Lukas

Task 4: Battery Housing Design

- Description: This task involves designing a rechargeable battery housing unit to power the Raspberry Pi 5, meeting specifications for weight, battery life, and heat dissipation. The power source will be a 3.7V, 5000mAh lithium-ion battery with a boost converter to provide a stable 5V output. CAD software will be used to design the housing, which will be fabricated using durable, lightweight materials like ABS plastic. Testing will include charging cycles, heat dissipation under load, and endurance tests to confirm 6+ hours of runtime for typical use.
- Deliverable: A tested battery housing capable of supporting the system’s power needs under real-world conditions.
- Lead: Jake
- Assisting: Lukas

Task 5: Wrist-Wearable Design

- Description: This task includes designing and building an ergonomic wrist-wearable device to house the ESP32 microcontroller, haptic motors, LED array, and photoresistor sensor. The ESP32 will handle motor control and feedback, while the LED array will increase the user's visibility to vehicles and pedestrians. The wearable will be designed in SolidWorks, fabricated with a flexible TPU material for comfort, and tested for fit, durability, and functionality. Feedback patterns from the motors will be integrated to convey directional cues based on object detection data.
- Deliverable: A fully assembled, wearable device tested for comfort, durability, and functionality.
- Lead: Lukas
- Assisting: Jake

Task 6: Training a New YOLOv3 Model

- Description: This task involves fine-tuning and training the YOLOv3 object detection model to recognize road signage and parse street text. Using a dataset collected from public sources, including the COCO dataset and custom images, the model will be trained on an NVIDIA GPU using BU’s Shared Computing Cluster. The goal is to achieve a detection accuracy above 90% for specific objects and text relevant to navigation. After training, the model will be optimized for deployment on the Raspberry Pi 5 using TensorFlow Lite to ensure efficient inference.
- Deliverable: A trained YOLOv3 model with improved recognition accuracy for signage and text.
- Lead: Jason
- Assisting: Shamir and Lukas

Task 7: Central Processing Unit Development

- Description: This task requires building a central processing unit (CPU) to integrate inputs from object detection, depth mapping, and speech processing. The

CPU, implemented on the Raspberry Pi 5, will run Python scripts to merge object detection and depth data and process user queries via a speech-to-text interface powered by Whisper.cpp. Outputs will be delivered through a text-to-speech system using the pyttsx3 library. Testing will ensure real-time processing (<1 second response time) and accurate feedback for user queries like “What is to my right?”
- Deliverable: A CPU capable of integrating inputs and providing accurate audio feedback.
- Lead: Lukas
- Assisting: Shamir and David

Task 8: Haptic Motor Tuning for Directional Feedback

- Description: This task involves calibrating the haptic motors to provide intuitive directional feedback based on object detection data. Using an ESP32 microcontroller, motor feedback will be mapped to object positions, ensuring motors on the user’s left or right activate based on the detected location of obstacles. Feedback intensity and duration will be adjusted using PWM signals for clarity. Testing will involve user trials to confirm the feedback is intuitive and effective for navigation.
- Deliverable: A calibrated system providing intuitive directional feedback to the user.
- Lead: David
- Assisting: Jake and Jason
Milestone | Completion Date | Associated Tasks
Dual Cameras Integrated | 01/31/2025 | Task 1.4
Housing Units Fabricated | 02/14/2025 | Tasks 1.7
Stereo Vision Algorithm Ready | 02/24/2025 | Task 2.8
YOLOv3 Model Trained | 03/03/2025 | Task 2.9
CPU Development Complete | 04/07/2025 | Task 3.5
Haptic Feedback Calibrated | 04/13/2025 | Task 4.3

### 6.0 Budget Estimate

Item | Description | Cost
1 | Teensy40 ESP32 Microcontroller | $23.80
2 | TinyPICO ESP32 Microcontroller | $130
3 | Bone Conduction Headphones with Microphone | $17.88
4 | Mini Vibration Motors DC 3V (x30) | $12.99
5 | Vibration Motors Coreless DC (x6) | $8.99
6 | ATtiny85 ESP32 Microcontroller | $1.66
7 | ESP32 S2 Mini Microcontroller | $8.99
8 | Seeed Studio Microcontroller | $9.90
9 | Raspberry Pi Zero W + Raspberry Pi Camera Module v2 | $44.95
10 | Raspberry Pi 5 | $88.00
11 | Raspberry Pi Camera Module v2 | $17.91
12 | Cap + Housing material | $75.00
13 | Wristband fabric material | $30.00
14 | LED rings (x2) | $32.00
| Total Cost | $394.02

Our vendors currently include Adafruit, Amazon, and PJRC Store, but may

expand in the future as we continue to iterate and upgrade key components of our Smart

System. The many microcontrollers purchased were used for extensive prototyping to

examine which would best fit our use case (size, power, connectivity, ease of use), and

given their relatively low price range, we opted to try a variety of microcontrollers to

assess the best decision for our final product. Various electronic components, wires,

soldering irons and solder, and cables were previously owned/borrowed from the ECE

lab.

### 7.0 Attachments

### 7.1 Appendix 1 – Engineering Requirements

Team # 29 Team Name: Smart Bears

Project Name: Smart System for Visually Impaired

Requirement | Specification | Value, range
System Performance | Response Time | < 1 second
| Object Detection Accuracy | > 90%
| Environmental Adaptation | < 10% accuracy variation between environments
Physical Properties | Total Weight | < 1 pound
| Wearable Dimensions | Cap: Standard hat sizer (21-24 inches)
| Operating Temperature | -10°C to 40°C
Power Requirements | Battery Life | ≥ 12 hours per charge
| Power Consumption | < 5W continuous operation
Signal Processing | Video Frame Rate | ≥ 30 fps
| Audio Latency | < 100 ms
| Haptic Signal Resolution | ≥ 8 distinct patterns
Reliability | Mean Time Between Failures | > 1000 hours
| Water Resistance | IP54 rating
| Drop Resistance | 1.5 m onto concrete
User Interface | Training Time | < 2 hours for basic operation
| Audio Output | 40-85 dB adjustable
| Haptic Feedback Strength | 0.5-2.0 G adjustable

### 7.2 Appendix 2 – Gantt Chart

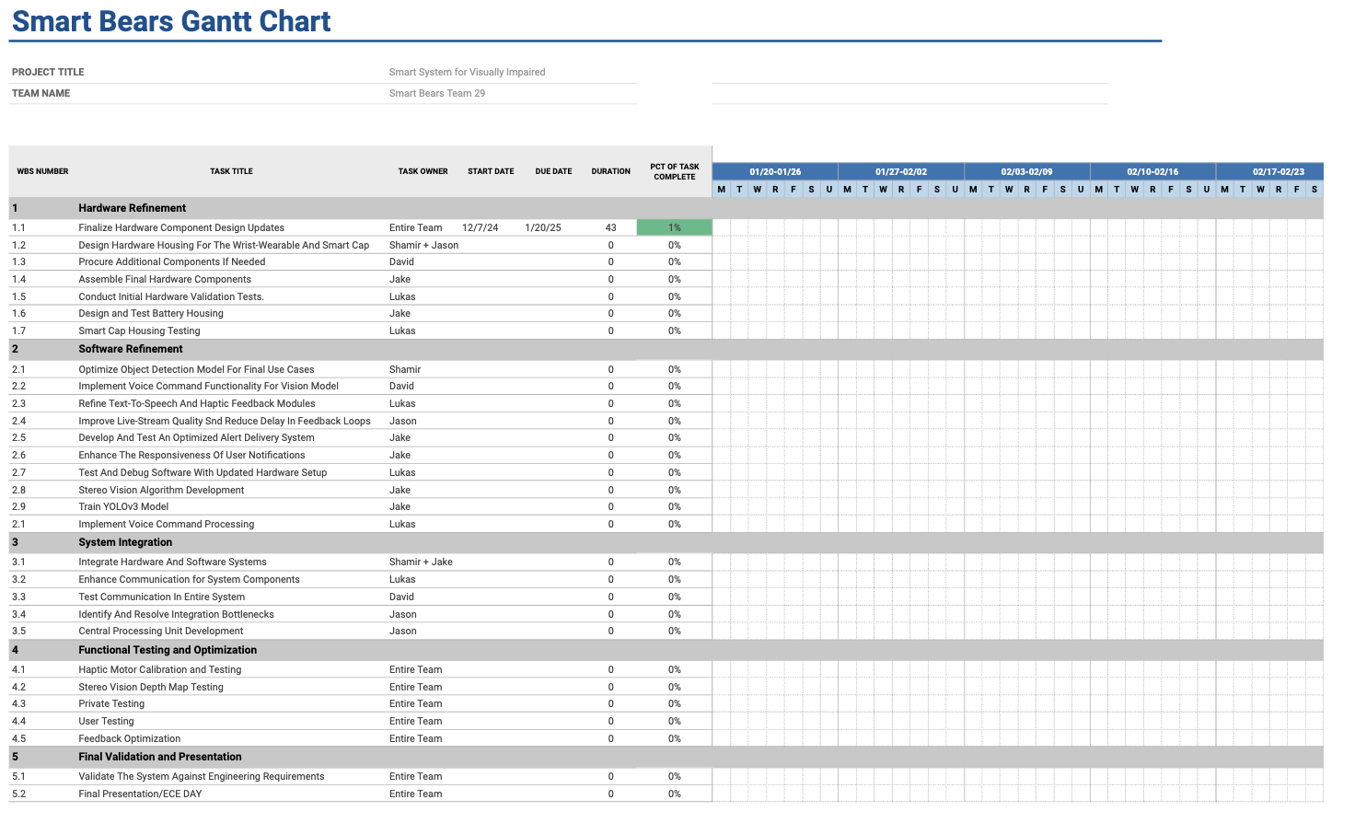
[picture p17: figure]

### 7.3 Appendix 3 – Technical References

Ask Samie. (n.d.). Ara - Mobility Aid for the blind and visually impaired. https://www.asksamie.com/products/ara?variant=43683470442704&currency=USD

Harrison, C., Horstman, J., Hsieh, G., & Hudson, S. (2012). Unlocking the expressivity of point lights. In Proceedings of the SIGCHI Conference on Human Factors in Computing Systems (pp. 1573-1582). Association for Computing Machinery.

Jiang, F., Yang, X., & Feng, L. (2021). A Wearable Navigation Device for Visually Impaired People Based on the Real-Time Semantic Visual SLAM System. Sensors, 21(4), 1536. https://doi.org/10.3390/s21041536

Justia Patents. (2022). Wearable Device Enablement for Visually Impaired User. https://patents.justia.com/patent/20220084433

National Federation of the Blind. (n.d.). Blindness Statistics. https://nfb.org/resources/blindness-statistics

National University of Singapore. (2023). AiSee - Mobility Aid for the blind and visually impaired. Futurity. https://www.futurity.org/aisee-visual-impairment-ai-device-3175252/

OrCam Technologies. (n.d.). OrCam MyEye 3 Pro. https://www.orcam.com/en-us/orcam-myeye-3-pro

Shen, J., Chen, Y., & Sawada, H. (2022). A Wearable Assistive Device for Blind Pedestrians Using Real-Time Object Detection and Tactile Presentation. Sensors, 22(12), 4537. https://doi.org/10.3390/s22124537

Silva, B., Costelha, H., Bento, L. C., Barata, M., & Assuncao, P. (2020). User-Experience with Haptic Feedback Technologies and Text Input in Interactive Multimedia Devices. Sensors, 20(18), 5316.

Srivastava, P., Tiwari, A., & Yadav, R. (2021). Design and Development of a Wearable Assistive Device Integrating a Fuzzy Decision Support System for Blind and Visually Impaired People. PMC, 8466919. https://www.ncbi.nlm.nih.gov/pmc/articles/PMC8466919/

Wearable Technologies. (2018). These New Generation of Wearables are Empowering Blind and the Visually Impaired.
https://wt-obk.wearable-technologies.com/2018/12/these-new-generation-of-wearables-are-empowering-blind-and-the-visually-impaired/ (https://wt-obk.wearable-technologies.com/2018/12/these-new-generation-of-wearables-are-empowering-blind-and-the-visually-impaired/)

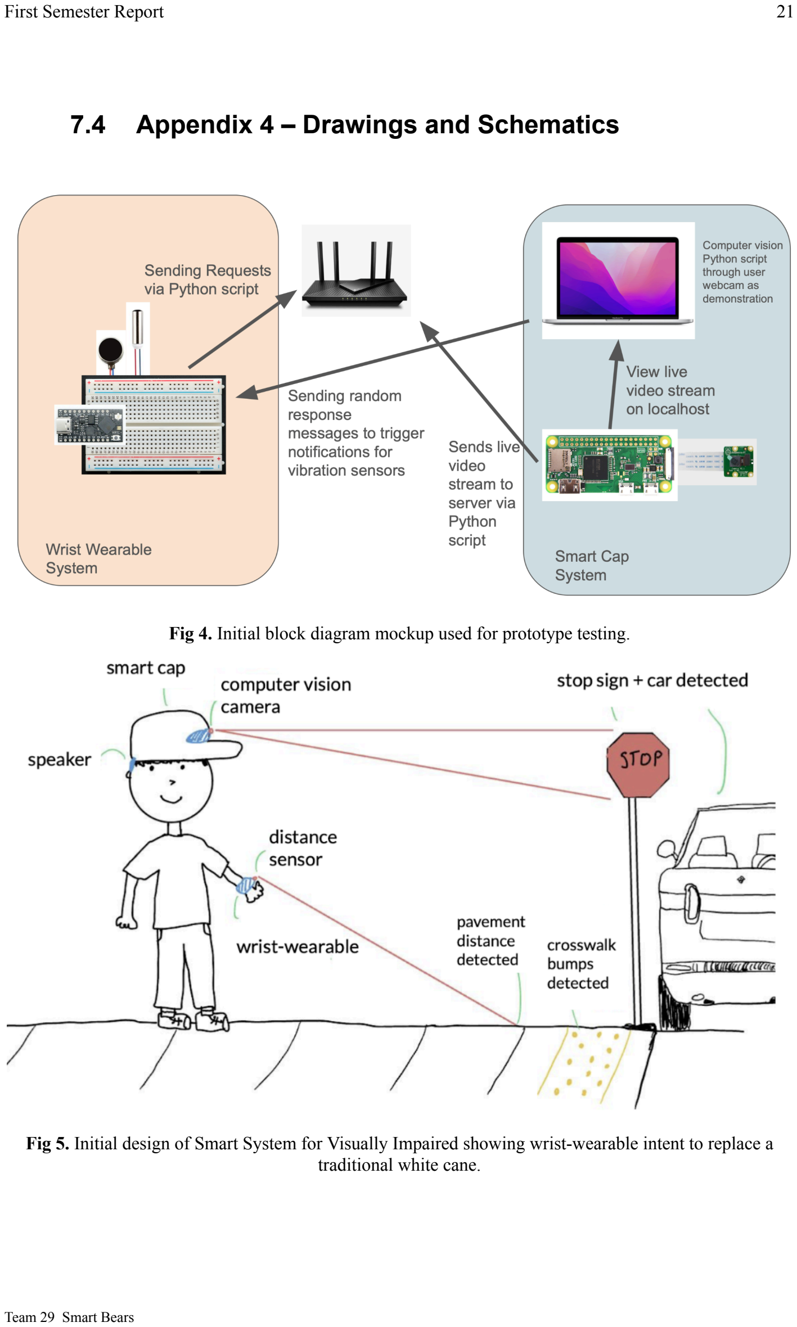
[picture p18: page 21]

### 7.4 Appendix 4 – Drawings and Schematics

Fig 4. Initial block diagram mockup used for prototype testing.

Fig 5. Initial design of Smart System for Visually Impaired showing wrist-wearable intent to replace a traditional white cane.

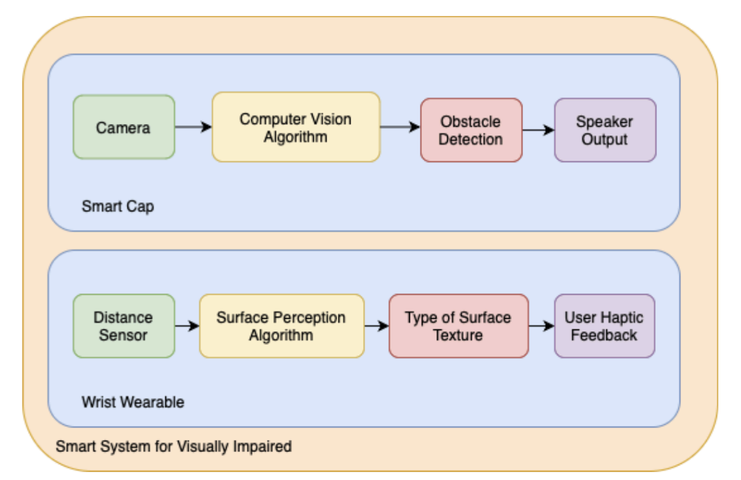
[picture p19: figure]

Fig 6. Initial simplified block diagram describing functionality of Smart Cap and Wrist-Wearable. Showcased at Shark Tank presentations.

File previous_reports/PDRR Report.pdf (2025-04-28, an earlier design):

## Boston University Electrical & Computer Engineering

EC463 Capstone Senior Design Project

## Problem Definition and Requirements Review

## Smart System for Visually Impaired

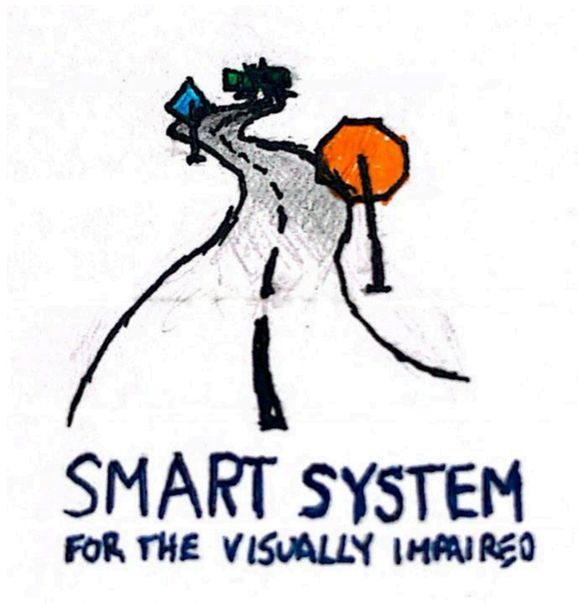
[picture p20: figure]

Submitted to

Michael Hirsch
mhirsch@bu.edu
8 Saint Mary's Street, Boston, MA 02215

by

Team 29
Smart Bears

Team Members

Lukas Chin | lchin10@bu.edu
Jake T. Lee | jaketlee@bu.edu
Shamir L. Legaspi | slegaspi@bu.edu
David Li | dav@bu.edu
Jason Li | jli3469@bu.edu

Submitted: 10/18/2024

Client Sign-Off _______________________________________

EC463 2024 PDRR Report | 2

## Smart System for Visually Impaired

Table of Contents

Project Summary | 2
1 | Need for this Project | 3
2 | Problem Statement and Deliverables | 4
3 | Visualization | 5
4 | Competing Technologies | 7
5 | Engineering Requirements | 8
6 | Appendix A References. | 10

Project Summary
Due to the effects of visual impairments on people’s ability to travel independently and access opportunities, people with visual impairments can face a reduction in quality of life. Current aids like white canes and guide dogs are often not accessible enough or do not provide enough improvement for them to be widely adopted. We propose the Smart System for the Visually Impaired as a solution to improve independent travel and navigation of environments. The system consists of two pieces, a wrist wearable and a head wearable. The wrist wearable will use distance sensors and haptic feedback to replace white canes as a hands-free solution. The head wearable will use a camera and computer vision to provide audio descriptions of the environment through a speaker to help users navigate the world.

### 1 Need for this Project

There are over 7 million people in the United States living with some sort of visual disability. Visual disabilities may make it hard for afflicted people to travel independently, reducing their engagement with society. This can also reduce their ability to participate in education, employment, and other activities. 27.7 percent of people with visual disabilities live below the poverty line, which is over double the rate of the total population. Over 70 percent of people with visual disabilities aged 21 to 64 are not employed full time compared to the estimated 16.5 percent of all people over 21 who are not employed full time. Current solutions like white canes, guide dogs, and other assistive technologies are not without their limitations. White canes leave users open to obstacles above the knee level. Guide dogs are not permitted in all scenarios. Other systems may be pricey. Overall, only 2 to 8 percent of visually impaired people use white canes and only about 2 percent use a guide dog. Existing solutions are not accessible enough or do not provide enough benefit to improve quality of life for people with visual impairments.

### 2 Problem Statement and Deliverables

Problem Statement:
Over 7 million people in the United States live with visual impairments that reduce their quality of life. This can affect their ability to engage socially and professionally, with poverty and unemployment rates among these people being much higher than the overall population. Less than 10 percent of people with visual impairments adopt alternative solutions like white canes and guide dogs. We strive to provide an accessibility solution that can improve the quality of life for those with visual impairments that will be easy to adopt.

Deliverables:
Our system aims to provide enhanced navigation and environmental awareness through a combination of wearable devices. The primary deliverable is a functional prototype consisting of two key components: a head-mounted device and a wrist-worn device, both equipped with sensors and feedback mechanisms to enhance the user's awareness of their environment.
The head-mounted device will feature a camera system to capture visual information about the surroundings. This will be complemented by speakers integrated into the headset design, allowing for audio feedback without impeding the user's natural hearing. The exact type and configuration of the camera and speakers will be determined during the development process to ensure optimal performance and user comfort.
The wrist-worn device will include at least one sensor to gather additional data about the user's movements and environment. This sensor will be chosen based on its ability to provide valuable information that complements the head-mounted device's capabilities. The wrist device will also incorporate a feedback mechanism to alert the user through tactile means.
As part of our intermediate deliverables, we will produce a finalized list of sensors for both the head and wrist devices. This list will be developed through careful research and testing to identify the most effective and appropriate sensors for our system's goals. Additionally, we will create basic circuit visualizations of the smart system, providing a clear overview of how the various components will interact and function together.

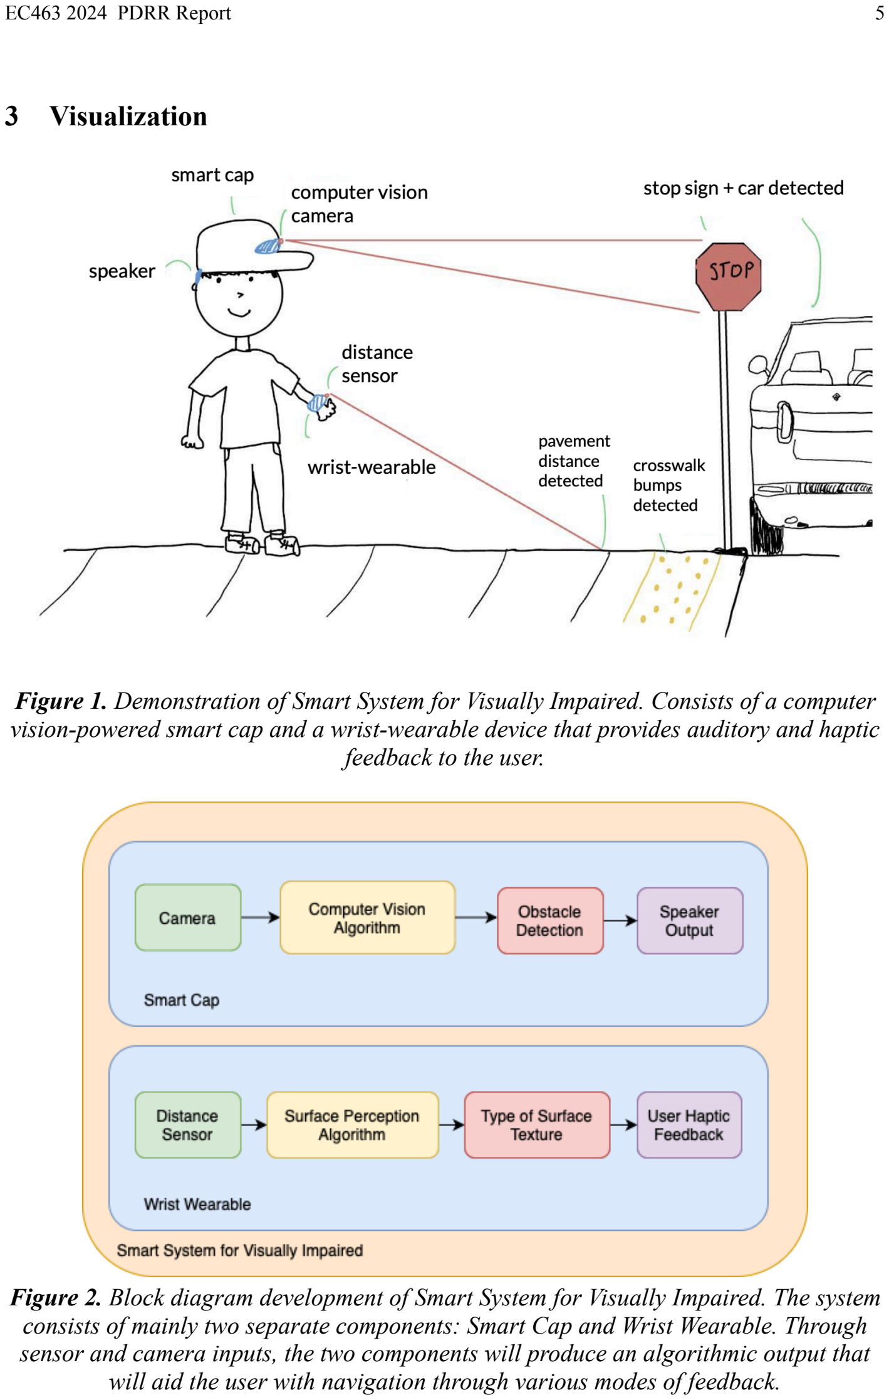
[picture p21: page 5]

### 3 Visualization

Figure 1. Demonstration of Smart System for Visually Impaired. Consists of a computer vision-powered smart cap and a wrist-wearable device that provides auditory and haptic feedback to the user.

Figure 2. Block diagram development of Smart System for Visually Impaired. The system consists of mainly two separate components: Smart Cap and Wrist Wearable. Through sensor and camera inputs, the two components will produce an algorithmic output that will aid the user with navigation through various modes of feedback.

Technical Progress Report | page 6

The Smart System for Visually Impaired is an innovative assistive technology designed to enhance the independence and safety of visually impaired individuals. At its core, the system consists of two main components: a smart cap and a wrist-wearable device, working in tandem to provide comprehensive environmental awareness and navigation assistance.
The smart cap is equipped with a computer vision camera that continuously scans the environment in front of the user. This camera feeds visual data into a sophisticated computer vision algorithm capable of detecting and identifying various objects, signs, and potential hazards. When obstacles or important visual cues are detected, such as stop signs or moving vehicles, the system alerts the user through a speaker integrated into the cap. This auditory feedback allows the user to navigate urban environments more safely, avoiding collisions and responding appropriately to traffic situations.
Complementing the smart cap is the wrist-wearable component, which adds another layer of sensory input and feedback. This device includes a distance sensor that analyzes the ground or surfaces in the immediate vicinity. The data from this sensor is processed by a surface perception algorithm, which can distinguish between different types of terrain or textures. Based on this analysis, the wrist device provides haptic feedback to the user, alerting them to changes in terrain, such as transitioning from pavement to grass, or warning of approaching curbs or steps.
The integration of these two components creates a powerful system that provides multi-modal feedback to visually impaired users. By combining visual information from the smart cap with tactile information from the wrist-wearable, users can build a more complete mental map of their surroundings. For example, the system can detect a crosswalk, alert the user through the speaker, and provide haptic feedback to guide them across safely. This comprehensive approach to environmental awareness significantly enhances the user's ability to navigate independently.

### 4 Competing Technologies

In the development of assistive devices for the visually impaired, we reviewed several competing products, patents, and technologies in order to gain a better understanding of the market to allow us to make more informed decisions on our project requirements. These technologies gave us the foundation for how we should shape the design of our project while also focusing on key elements such as real-time processing, portability, and sensor integrations.
The OrCam MyEye 3 Pro, for instance, is a wearable device designed to assist users by reading text aloud, recognizing faces, and identifying objects. This product’s emphasis on a lightweight wearable design and real-time image processing highlights the need for portability and responsive feedback mechanisms, elements that we are looking to incorporate into our project.
In addition to products, we also reviewed patents such as US Patent
20220084433, which is described as an AI-powered smart backpack. This system combines multiple sensors to provide navigational assistance, pointing out the importance of sensor integration in wearable technology. By incorporating sensor inputs, the backpack allows for the accurate detection of obstacles while providing haptic feedback to the user. Through the insight of this patent, we were guided in our decision to implement light wearable devices in the form of a wrist-worn sensor to provide the user with obstacle detection and haptic feedback.
After researching many competing technologies, we were able to gain a better understanding of what we should implement as several key requirements for our project. First, real-time feedback is a critical key requirement for users to rely on fast and accurate feedback. This ensures that the user can navigate safely using our device. Our system will prioritize low-latency processing to meet this need. Next, the combination of sensors helps the user gather a comprehensive understanding of the surroundings of the environment. Finally, portability was also a key requirement to allow the user to easily use the devices. Ensuring that the device is non-intrusive and easy to use in their day to day life allows for a wide range of users.

### 5 Engineering Requirements

### 5.1 Tactile Feedback

1. The system must deliver haptic signals through vibration motors embedded in the glove’s fingers and palm.
2. The haptic feedback must distinguish between at least three proximity ranges (e.g., near, mid-range, far), corresponding to the intensity of the vibration.
3. The haptic feedback must respond within 100 milliseconds of detecting an object within a 1-meter range.

### 5.2 Camera-Based Vision

1. The camera must be integrated into a wearable device (smart cap) and capture real-time video at a resolution of at least 720p.
2. The system must provide real-time speech output for text detection from objects such as signs, with a processing time of under 1 second.
3. The camera must support low-light environments and be functional in lighting as low as 10 lux.

### 5.3 Real-Time Feedback

1. The system must provide real-time feedback (via haptic or auditory signals) within 100 milliseconds of detecting an obstacle.
2. The system must distinguish between different types of objects, including static and moving, and provide distinct feedback for each type.
3. The system must operate continuously for at least 12 hours on a single charge, ensuring portability for all-day use.

### 5.4 Surface Scanning

1. The glove’s infrared sensors must detect ground obstacles up to 1 meter ahead and provide either haptic or auditory feedback within 100 milliseconds.
2. The system must accurately identify obstacles with at least 90% detection accuracy in both indoor and outdoor environments.

### 5.5 Portability and Usability

1. The combined weight of the smart glove and smart cap must not exceed 300 grams.
2. The system must be comfortable for users to wear for up to 12 consecutive hours, with breathable materials for the glove and an adjustable fit for the cap.
3. The system must require no more than 30 minutes of user training for effective operation.

### 5.6 Power and Durability

Technical Progress Report | page 9
1. The system must operate on a rechargeable battery that provides at least 12 hours of continuous use on a single charge.
2. The device must be water-resistant, withstanding exposure to light rain and water splashes, meeting the IPX4 standard.
3. The system must endure drops from a height of 1.5 meters without performance degradation.

### 5.7 Safety and Compliance

1. The feedback mechanism (vibrations or sounds) must be subtle enough to prevent discomfort or harm to the user while remaining noticeable.
2. The device must comply with ADA (Americans with Disabilities Act) regulations and FCC (Federal Communications Commission) standards to ensure safety and accessibility.

6 Appendix A References.

1. National Federation of the Blind. (n.d.). Blindness Statistics. https://nfb.org/resources/blindness-statistics
2. National University of Singapore. (2023). AiSee - Mobility Aid for the blind and visually impaired. Futurity. https://www.futurity.org/aisee-visual-impairment-ai-device-3175252/
3. OrCam Technologies. (n.d.). OrCam MyEye 3 Pro. https://www.orcam.com/en-us/orcam-myeye-3-pro
4. Ask Samie. (n.d.). Ara - Mobility Aid for the blind and visually impaired. https://www.asksamie.com/products/ara?variant=43683470442704&currency=US D (https://www.asksamie.com/products/ara?variant=43683470442704&currency=USD)
5. Shen, J., Chen, Y., & Sawada, H. (2022). A Wearable Assistive Device for Blind Pedestrians Using Real-Time Object Detection and Tactile Presentation. Sensors, 22(12), 4537. https://doi.org/10.3390/s22124537
6. Jiang, F., Yang, X., & Feng, L. (2021). A Wearable Navigation Device for Visually Impaired People Based on the Real-Time Semantic Visual SLAM System. Sensors, 21(4), 1536. https://doi.org/10.3390/s21041536
7. Wearable Technologies. (2018). These New Generation of Wearables are Empowering Blind and the Visually Impaired. https://wt-obk.wearable-technologies.com/2018/12/these-new-generation-of-wearables-are-empowering-blind-and-the-visually-impaired/ (https://wt-obk.wearable-technologies.com/2018/12/these-new-generation-of-wearables-are-empowering-blind-and-the-visually-impaired/)
8. Srivastava, P., Tiwari, A., & Yadav, R. (2021). Design and Development of a Wearable Assistive Device Integrating a Fuzzy Decision Support System for Blind and Visually Impaired People. PMC, 8466919. https://www.ncbi.nlm.nih.gov/pmc/articles/PMC8466919/
9. Justia Patents. (2022). Wearable Device Enablement for Visually Impaired User. https://patents.justia.com/patent/20220084433

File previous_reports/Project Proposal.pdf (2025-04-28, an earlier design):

EC463 Senior Design Project Proposal: Smart Assistive System for the Visually Impaired Lukas Chin, Shamir Legaspi, David Li, Jason Li

Introduction
In an effort to enhance the independence and quality of life for visually impaired individuals, our team proposes the development of an innovative smart assistive system. This system comprises two key components: a smart glove and a smart cap. By combining cutting-edge technologies such as infrared sensing, haptic feedback, computer vision, and artificial intelligence, our project aims to provide a comprehensive solution for spatial awareness and environmental interaction.

Project Overview
The smart assistive system consists of two main components:
- Smart glove equipped with infrared sensors for proximity detection
- Smart cap featuring an integrated camera for real-time environmental scanning

Smart Glove Details
The smart glove will be designed to augment the user's sense of touch and spatial awareness. The smart glove will ideally replace conventional white canes as a hands-free alternative.

Key features include:
- Infrared Sensors: Strategically placed sensors will detect features of the ground.
- Haptic Feedback: Vibration motors embedded in the fingertips and palm will convey proximity information through varying intensities and patterns.
- Microcontroller: A low-power, compact microcontroller will process sensor data and control haptic outputs.
- Ergonomic Design: The glove will be crafted from breathable, flexible materials to ensure comfort during extended use.

Smart Cap Details
The smart cap will serve as the system's "eyes," providing crucial visual information to the user.

Key features include:
- High-Resolution Camera: A wide-angle camera capable of capturing the user's field of view in various lighting conditions.
- Embedded Computer: A powerful, energy-efficient single-board computer (e.g., Raspberry Pi) for real-time image processing and AI inference.
- Computer Vision Algorithms: Custom-trained models for detecting and classifying objects and reading text.
- Audio Feedback: Speakers integrated into the cap's structure for discreet audio cues without obstructing environmental sounds.

- Gesture Detection: Allows users to fine tune the behavior of the smart assistive system for different situations (environment navigation, reading text, etc).

Technical Challenges and Solutions
- Power Management: Optimizing battery life through efficient coding and low-power components.
- Real-time Processing: Utilizing edge computing techniques to minimize latency in object detection and feedback.
- Accuracy in Varied Environments: Developing robust algorithms that perform well in diverse lighting and weather conditions.
- User Interface: Creating an intuitive, non-visual interface for system control and customization.

Societal Impact
This smart assistive system has the potential to significantly improve the lives of visually impaired individuals by:
- Enhancing independence in daily activities through an innovative hands-free alternative
- Improving safety in navigation and obstacle avoidance
- Increasing access to written information in the environment

Final Deliverables
- Functional Prototype: One system of a smart glove and a smart cap
- Software Package: Embedded software for the glove and cap’s microcontroller
- Technical Documentation: Detailed system architecture and component specifications
- Project Report: Comprehensive documentation of the design process
- Presentation Materials: Project demonstration video
- Future Development Roadmap: Suggestions for further enhancements and features

Conclusion
The Smart Assistive System for the visually impaired represents a significant step forward in assistive technology. By combining advanced sensing technologies with intuitive feedback mechanisms, this project aims to create a practical, user-friendly solution that can make a real difference in the lives of visually impaired individuals. Our team is committed to delivering a high-quality prototype that demonstrates the potential of this innovative approach to assistive technology.

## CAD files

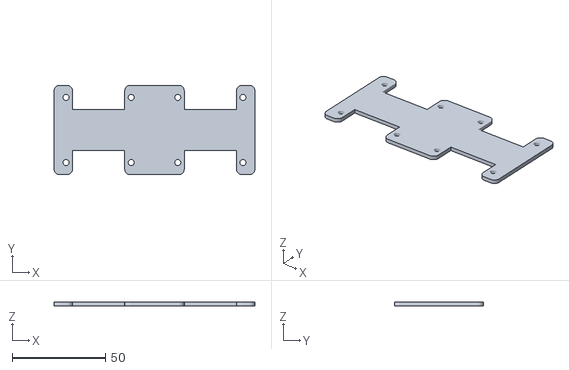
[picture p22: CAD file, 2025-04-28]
housing_schematics/StereoCamMountV2.stl
108.0 x 48.0 x 2.00

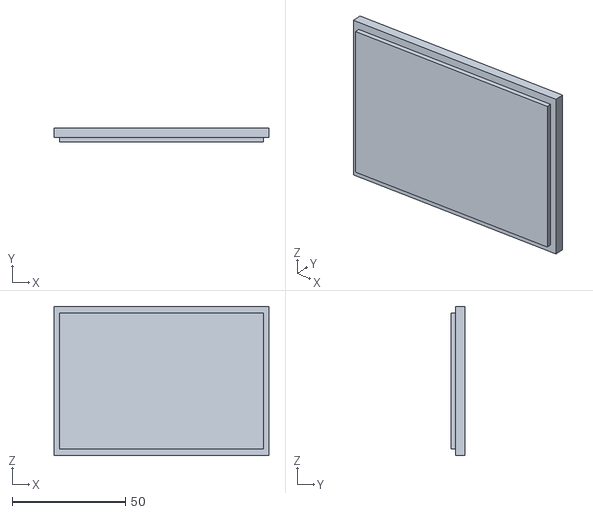
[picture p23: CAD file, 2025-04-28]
housing_schematics/RaspberryPi5HousingLid.stl
95.0 x 6.00 x 66.0

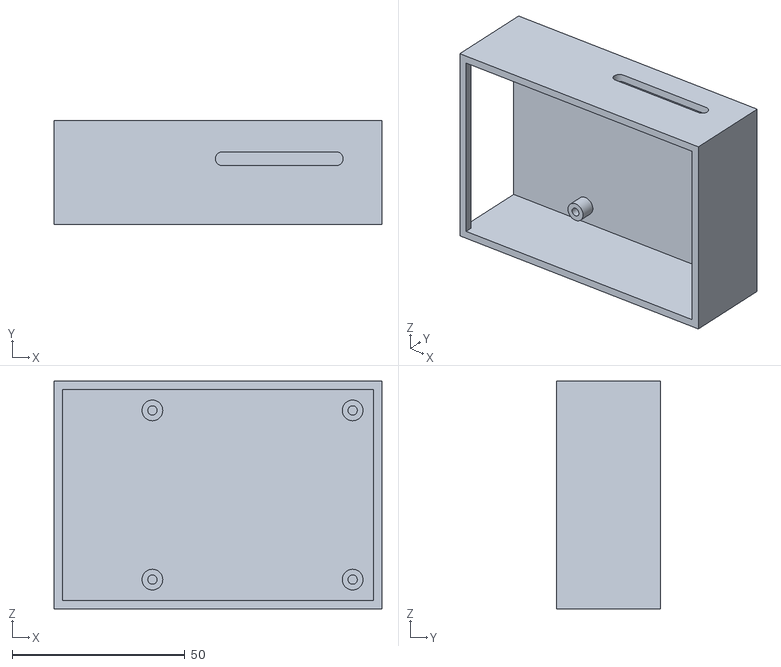
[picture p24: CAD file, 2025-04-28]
housing_schematics/RaspberryPi5Housing.stl
95.0 x 30.0 x 66.0

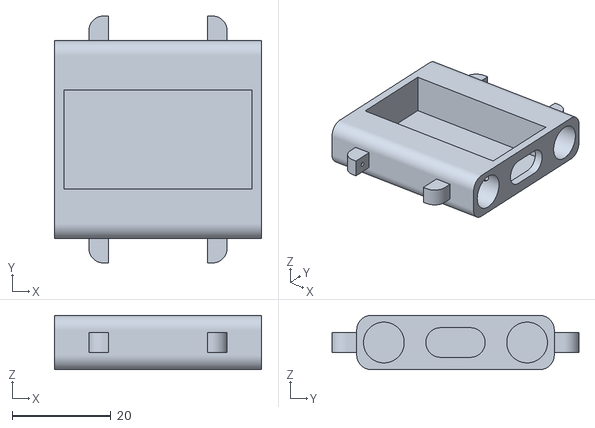
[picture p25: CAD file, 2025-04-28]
housing_schematics/WristWearableHousing.stl
42.0 x 50.0 x 11.0

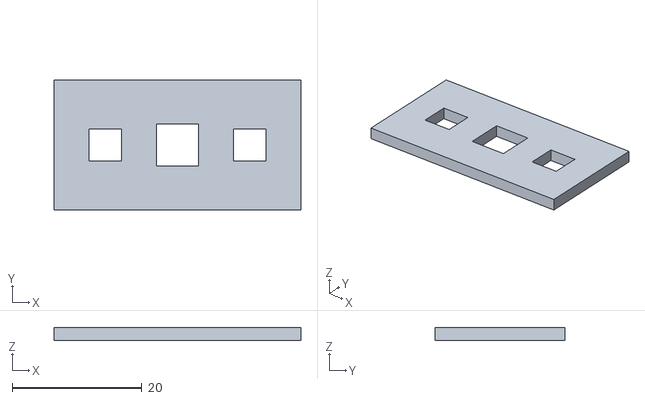
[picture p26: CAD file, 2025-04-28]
housing_schematics/WristWearableLid.stl
38.0 x 20.0 x 2.00

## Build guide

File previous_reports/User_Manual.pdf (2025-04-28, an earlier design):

## Boston University Electrical & Computer Engineering

EC464 Capstone Senior Design Project

## User's Manual

## Smart System for Visually Impaired

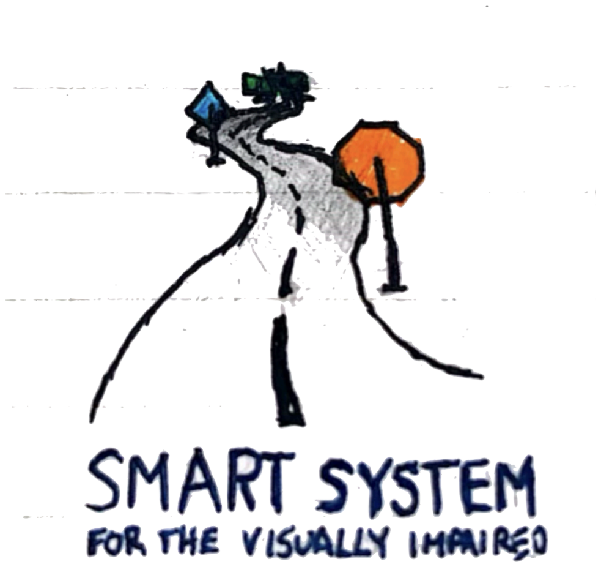
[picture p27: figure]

by

Team 29
Smart Bears

Team Members

Lukas Chin lchin10@bu.edu
Jake Lee jaketlee@bu.edu
Shamir Legaspi slegaspi@bu.edu David Li dav@bu.edu
Jason Li jli3469@bu.edu

Submitted: 04/18/2025

User's Manual | 2

### Smart System for Visually Impaired

Table of Contents

Executive Summary | ii
1 | Introduction | 1
2 | System Overview and Installation | 2
2.1 | Overview block diagram | 2
2.2 | User interface. | 3
2.3 | Physical description. | 3
2.4 | Installation, setup, and support | 6
3 | Operation of the Project | 7
3.1 | Operating Mode 1: Normal Operation | 7
3.2 | Operating Mode 2: Abnormal Operations | 7
3.3 | Safety Issues | 7
4 | Technical Background | 9
5 | Relevant Engineering Standards | 11
6 | Cost Breakdown | 13
7 | Appendices | 14
7.1 | Appendix A - Specifications | 14
7.2 | Appendix B – Team Information | 16
Team 29 (Smart Bears) | April 18, 2025

Technical Progress Report | 3

Executive Summary
Smart System for Visually Impaired Team 29
In the United States, there are over 20 million people who are visually impaired, with about 1 million of those with blindness. Every day these visually impaired individuals
have trouble navigating their surroundings with many needing to use white canes or
guide dogs for assistance. While white canes and guide dogs provide great aid for
everyday navigation, our Smart System for Visually Impaired offers even greater enhanced mobility through wearable technology that combines obstacle detection, real time object recognition, live haptic and auditory feedback, and speech control. Smart System for Visually Impaired uses cutting edge computer vision techniques to detect everyday hazards, and it listens to the user for quick and automatic speech input. Our Smart System for Visually Impaired combines a Smart Cap and an Intelligent Wrist-Wearable wirelessly to provide the user with exceptional environmental awareness and navigation confidence.
Team 29 Smart Bears | April 18, 2025

User's Manual | 1

### 1 Introduction

Smart System for Visually Impaired was created to address the difficulties users may encounter with existing aids for those with visual impairments. White canes and guide dogs provide visually impaired individuals a great deal of autonomy, but may be difficult to use to the fullest extent in unfamiliar environments. By providing a holistic overview of the environment and highlighting key safety and risk features, the Smart System for Visually Impaired can work in tandem with existing aids to grant further autonomy.
The main function of the project is to transform visual information into auditory and haptic information so that it would be consumable for visually impaired users. The choice of using auditory and haptic media guided many of the decisions and constraints of the design from the user interface to the latency requirements.
Overall, the project combines IoT, computer vision, and LLM prompt engineering into a user-friendly interface that helps users learn about their surroundings while also making them more visible to others.
The IoT aspect of the system allows for the smart cap and wrist wearable to seamlessly interact. A single button press from the user allows a pipeline of actions to be set off across both devices involved. Part of this pipeline includes capturing images and processing them through computer vision. Using OpenCV and its built-in Stereo Block Mapping, the system is able to obtain relative depth information. With raw images and relative depth mapping, the next step in the pipeline is the LLM prompting. The emphasis on natural language in large language models makes it possible to extract the most relevant information from the inputs given where defining relevance algorithmically may be difficult.
Given a stable connection, the processing portion of the system’s workflow has been demonstrated to take under 3 seconds on average from button press to the start of audio and haptic information being transmitted to the user. Because it takes much longer to output and consume audio and haptic information compared to visual information, reducing the processing time provides diminishing returns. This is also a key reason why the system is a supplement to existing aids and not a replacement. There is simply too much information to be conveyed through the media of choice.
The resulting system is easily equipped and beginner-friendly. The complex processing involved in the system is hidden from the user behind a simple button push. The combination of haptic and audio information provides the user with quick, simple information and also slower, more in-depth information.
Team 29 (Smart Bears) | April 18, 2025

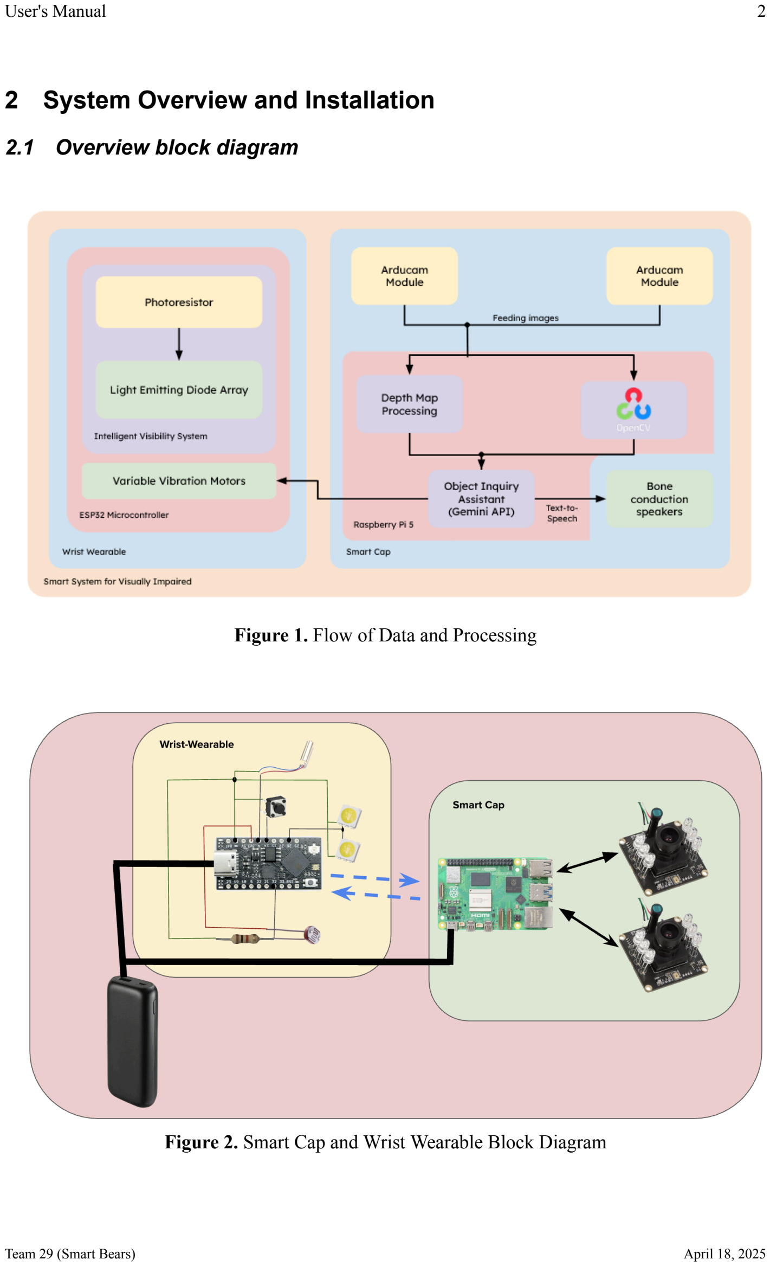
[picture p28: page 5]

User's Manual | 2

### 2 System Overview and Installation

### 2.1 Overview block diagram

Figure 1. Flow of Data and Processing

Figure 2. Smart Cap and Wrist Wearable Block Diagram

Team 29 (Smart Bears) | April 18, 2025

2.2 User interface.

The user interacts primarily through the Wrist-Wearable, which features a central push button used to trigger environmental queries. Feedback is returned via two modalities: a bone conduction headset for spoken descriptions, and vibration motors embedded in the wrist module to signal proximity-based urgency. A light sensor regulates the IVS: in low-light conditions, white LEDs on the wrist activate automatically, improving visibility without causing glare.

2.3 Physical drawings.

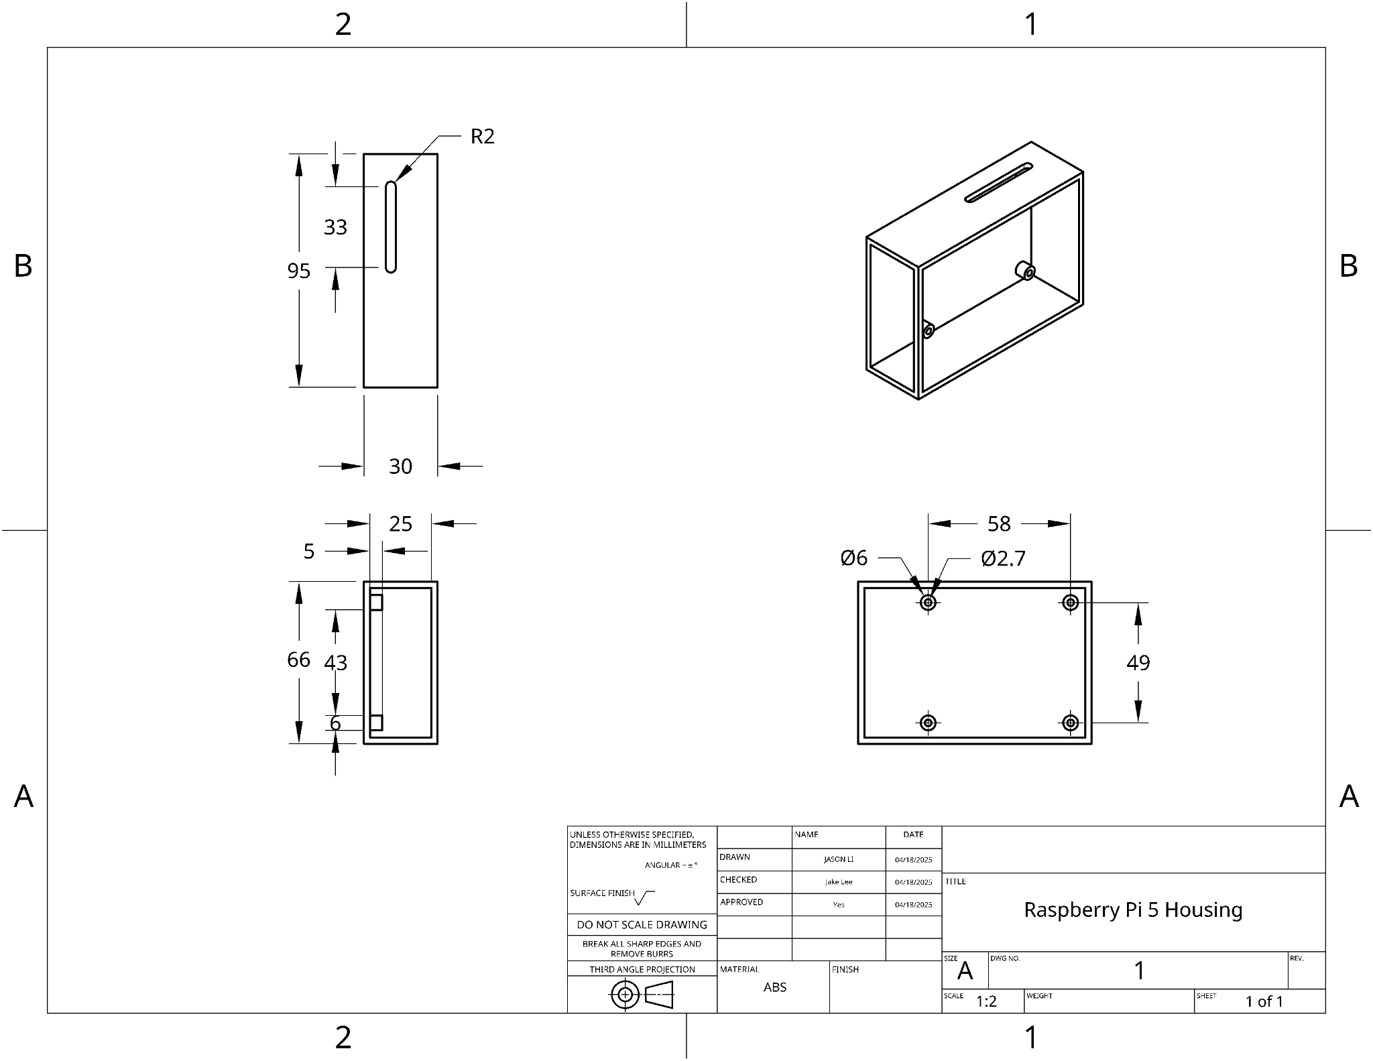
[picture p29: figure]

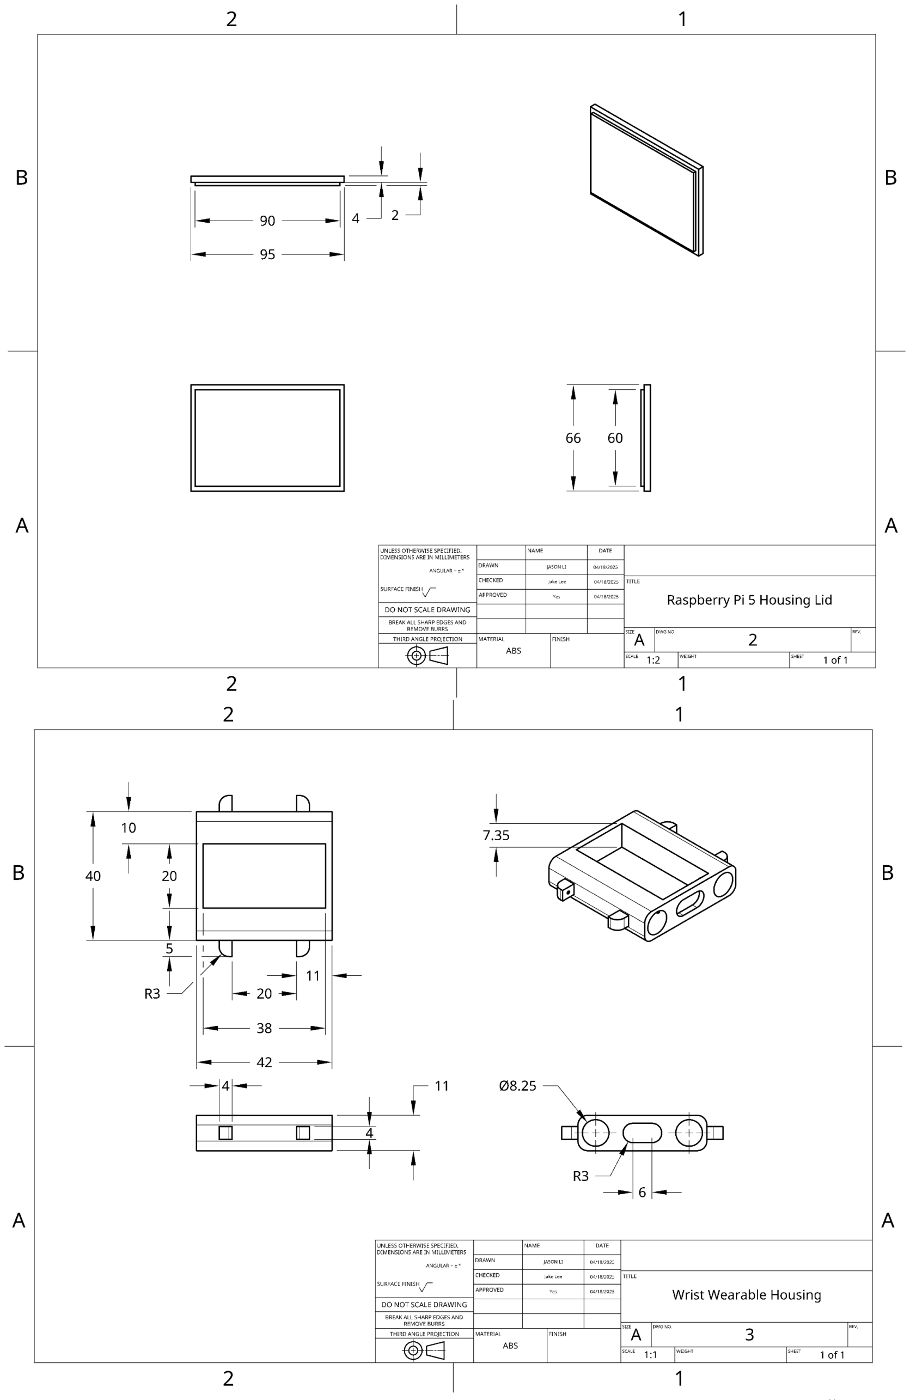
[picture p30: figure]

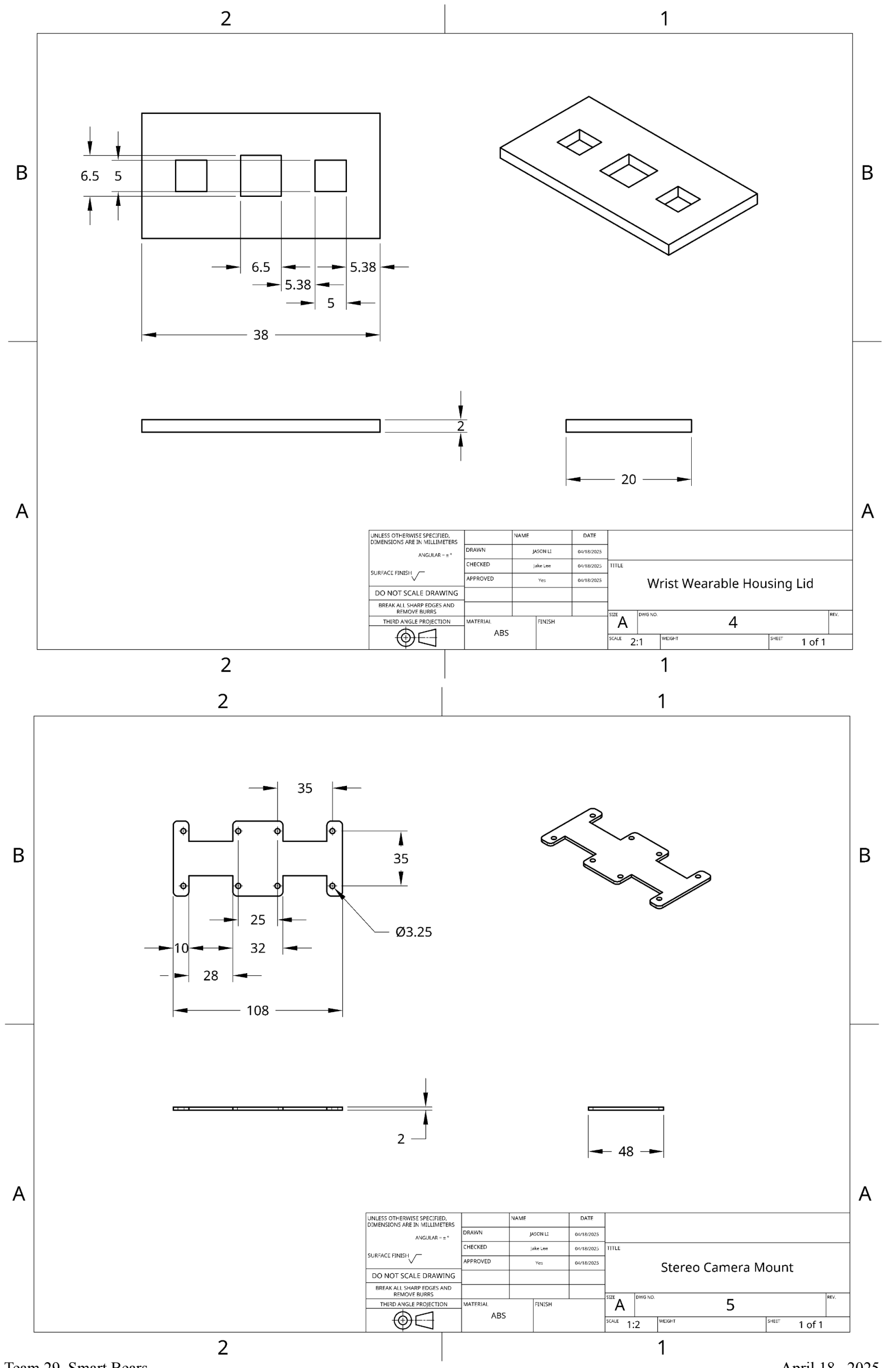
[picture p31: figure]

### 2.4 Installation, setup, and support

Hardware Setup:

1. Mount the stereo cameras on the Smart Cap and connect to the Raspberry Pi’s USB ports.
2. Secure the Raspberry Pi in a weather-protected case and power it using a 5V portable battery.
3. Strap the Wrist-Wearable to the user’s wrist, ensuring the photoresistor is unobstructed and the push button is easily accessible.
4. Connect both the ESP32 and Raspberry Pi to the same WiFi network.
5. Pair the bone conduction headset to the Raspberry Pi via Bluetooth.

Software Setup:

1. SSH into the Raspberry Pi or use a connected monitor and keyboard.
2. Navigate to the project root directory on the Pi.
3. Run the following scripts in order:
- pi.py: Calls submodules to conduct all involved processes. Waits for a request from the UDP socket to begin image processing workflow. Captures stereo images and uses pregenerated camera calibration parameters to generate a depth map. Sends the visual processing output to an LLM and outputs the response through bluetooth speakers and initiates a buzzing signal to the wrist-wearable.
4. Ensure the ESP32 is flashed with the wrist-wearable firmware, and has open UDP ports.
- esp.py: Handles the UDP communication for the buzzer and LEDs
5. Press the Wrist-Wearable button to initiate the query-response loop. Confirm system activation by verifying auditory and haptic feedback.

For technical support, users should review setup logs, ensure UDP port accessibility between devices, confirm Bluetooth pairing, and consult debug outputs in each script’s terminal window.

User's Manual | 7

### 3 Operation of the Project

### 3.1 Operating Mode 1: Normal Operation

During normal operation, the user points their head in a desired direction and presses the wrist button. The cameras capture synchronized images, which are processed by the Raspberry Pi to generate depth maps using OpenCV. These images and analysis are sent to an LLM through the Gemini API, which generates descriptive speech delivered through the bone conduction headset. If nearby obstacles are identified, the Wrist-Wearable vibrates accordingly. The IVS will activate the LED array in dim environments to assist with visibility.

### 3.2 Operating Mode 2: Abnormal Operations

Due to the system running via Bluetooth and WiFi, there are occurrences where the communication between the Smart Cap and the Wrist-Wearable is lost. In these cases, the system may temporarily fail to transmit signals from the wrist button to the Raspberry Pi or may drop the response signal returning from the Smart Cap. This can result in unregistered user input or a lack of audio and haptic feedback. To recover from such a state, users should first ensure that both devices are still connected to the same WiFi network. If needed, the user can restart the ESP32 microcontroller or reboot the Raspberry Pi to reinitialize the UDP socket connection.

In the case that the system involves failure in Bluetooth communication with the bone conduction headset. If the headset does not deliver speech output following an object inquiry, users should check the Bluetooth pairing status and recharge the headset if the battery is low. Re-pairing the headset through the Raspberry Pi’s Bluetooth settings typically resolves this issue.

Currently there are no hardware reset buttons, so user intervention to manually ensure that the system is connected is required. In the event of persistent issues, users are advised to go back to the setup and ensure everything is running properly.

### 3.3 Safety Issues

With any wearable device there are safety concerns. Since we have two stereo mounted cameras connected to our Raspberry Pi via USB there may be choking hazards if the wires get tangled. Additionally, if the cameras overheat it may cause discomfort to the user’s forehead. One of our design choices for the Raspberry Pi was to move it away from the user's head into our hip pack. This would reduce the risk of overheating from the microcontroller and take away weight from the head mount also reducing the risk of neck strain.

As for the wrist wearable, the main implications are overheating and wrist discomfort. The intensity of the vibration of the haptic feedback may be too

Team 29 (Smart Bears) | April 18, 2025

overwhelming for some users. Also, it could reduce stability and mobility of the hand due to the rapid vibrations. The intelligent visibility system poses a risk as it could cause discomfort to the users’ eyes and people in the surroundings. The wrist strap also brings up another point of concern as the elastic nylon could rub against the users’ skin and lead to rash, as well as if the strap is too tight could be a point of discomfort.

In addition, the suggestions from the smart system should be heeded with the user’s discretion. Our system gives descriptions and advice, though the correct course of action may change between when the system makes a decision and when the user takes action. At any point, the user’s greater judgement should be taken when making any navigational decisions.

User's Manual | 9

### 4 Technical Background

The foundation of the Smart System lies in its fusion of stereo vision, real-time object detection, and natural language understanding. The stereo depth sensing leverages two camera inputs to simulate human binocular vision. The disparity between the images is calculated using OpenCV’s block matching algorithm to produce a gradient-based heatmap that conveys object distance in visual form.

Many parameters had to be tuned to improve the accuracy of the disparity mapping. Stereo-based depth mapping relies on block-matching algorithms that compare pixel blocks between left and right images to establish correspondences and calculate disparity. The primary challenge occurs in regions with low texture variation, where the algorithm struggles to find unique matches, resulting in sparse depth information that often outlines objects well but leaves their interiors empty. This happens because the StereoBM algorithm employs a texture threshold parameter which filters out homogeneous regions where establishing reliable correspondences is difficult. At object boundaries, additional complications arise from what's known as "speckle noise" -artifacts created when matching windows capture both foreground and background elements simultaneously, causing local regions of inconsistent disparity values

The technical solution involves careful tuning of several interconnected parameters. The texture threshold directly controls how aggressively low-texture regions are filtered, with higher values creating more gaps but reducing noise. Block size determines the area used for matching; larger blocks improve stability in uniform regions but sacrifice detail. Speckle filtering parameters (speckleWindowSize and speckleRange) help eliminate noise by defining connected component constraints - the window size determines how large a region must be to avoid being filtered out, while the range establishes how much disparity variation is acceptable within that region. Additional parameters like uniqueness ratio, pre-filter size, and pre-filter cap also affect the algorithm's ability to balance between noise reduction and information preservation. Effectively addressing depth mapping gaps requires finding the optimal balance between these parameters to ensure sufficient texture sensitivity while maintaining robustness against noise and false matches.

For object recognition, the system relies on the multimodal input capabilities of the Gemini API. The raw images are passed along with depth information and optional speech input to an LLM via a lightweight Python client which manages Gemini API

Team 29 (Smart Bears) | April 18, 2025

interactions. To ensure that the LLM responses align with what is considered useful, thorough prompt engineering was conducted. To minimize the processing and token costs for the Gemini API calls, the images taken are sized down before being passed. Gemini separates images into 512 x 512 pixel chunks, so reducing the image size to something that can fit into a 1 x 2 grid of 512 x 512 pixel chunks maintains a balance between detail and cost. Performing this size reduction after performing depth mapping allows for the depth mapping to be very accurate.

A system prompt is passed along with every call to the API. This prompt highlights to the LLM what it’s role is and what its response format should be. In addition, the system prompt also tells the LLM how to interpret the depth map passed to it. It also dictates what the LLM should consider as most relevant when responding. We determined that distance, object type, proximity to the user’s path, and surrounding context were all necessary for determining what should be included in the response, and the system prompt highlights these findings to the LLM.

After receiving the response, text-to-speech feedback is generated using system-level utilities like pyttsx3 or custom audio synthesis pipelines, which are then streamed via Bluetooth to the headset.

Communication between the Wrist-Wearable and the Smart Cap is established using UDP sockets for minimal latency and maximum reliability in a wireless setting. All modules are designed to run concurrently, ensuring smooth end-to-end interactions even under constrained computational resources.

The Wrist-Wearable makes use of GPIO control and PWM to control the input of the button and photoresistor and the output of the LEDs and the buzzer. The photoresistor is paired with its matching 10k Ohm resistor along an analog pin, so that the voltage drop can be read to understand the brightness of the surroundings.

User's Manual | 11

### 5 Relevant Engineering Standards

The Smart System for Visually Impaired incorporates various engineering standards to ensure safety, reliability, and accessibility. These standards guide the development of both hardware and software components, providing a framework that supports the system's functionality while meeting industry requirements.

The wearable components of our system adhere to IEEE 360-2022, which outlines requirements for wearable consumer electronic devices. This standard ensures our devices meet basic safety, comfort, and wearability criteria through clear technical guidelines and test methods. To address general electrical safety, we follow IEC/UL 62368-1, which applies to audio/video and information technology equipment. This standard supports the safety of our head-mounted and wrist-worn electronic components during both normal operation and fault conditions.

While our system uses a standard commercial-grade portable battery to power the wearable and head-mounted components, we still followed best practices and relevant standards to ensure safety. We follow UL 1642 and IEC 62133-2, which define requirements for lithium batteries in consumer electronics. These standards cover aspects such as overcurrent protection, thermal regulation, and failure containment.

Additionally, our team adhered to course safety policies for lithium battery usage as outlined by the course faculty. While our battery posed significantly less risk than raw lithium cells, we observed the following:

- Battery terminals were not exposed; no alligator clips were used.
- No charging occurred without pre-approved charging setups.
- Commercial battery packs were only charged using manufacturer-provided chargers.
- Batteries were never left unattended during charging.

Our system employs a UDP-based communication protocol over WiFi, enabling real-time data exchange between the TinyPico ESP32 in the wrist wearable and the Raspberry Pi 5 in the head-mounted unit. UDP allows for low-latency performance, which is critical for time-sensitive haptic feedback. Our stereoscopic vision algorithm adheres to established methodologies for generating depth maps. Both implementations are based on current industry best practices in computer vision and embedded AI.

To ensure reliable and secure communication when sending requests to the Gemini API, our system follows established API development and integration best practices. This includes implementing rate limiting, handling timeouts and retries, and validating input/output

Team 29 (Smart Bears) | April 18, 2025

payloads to prevent malformed requests. Authentication is securely managed using appropriate tokens, and all requests are made over HTTPS to ensure data confidentiality and integrity. These practices ensure robust integration and minimize the risk of communication failures or security vulnerabilities during real-time operation. While the current prototype does not retain any user data, our architecture is built with potential future data logging in mind. In such cases, the system is designed to comply with appropriate data protection regulations and privacy best practices to safeguard sensitive information.

Designed specifically for visually impaired users, our system aligns with the Assistive Technology Act and other accessibility guidelines to ensure usability and inclusion. We considered research-based best practices for mobility aids in urban environments during the design of our wearable devices. Interface elements such as button input, haptic feedback, and audio cues follow established accessibility standards. Haptic feedback is designed with distinct vibration patterns based on tactile interface standards to enhance user differentiation and interaction without requiring vision.

### 6 Cost Breakdown

Project Costs for Production of Beta Version (Next Unit after Prototype)
Item | Quantity | Description | Unit Cost | Extended Cost
1 | 1 | Raspberry Pi 5 w/ 16 GB of RAM | $159.99 | $159.99
2 | 1 | TinyPICO ESP32 | $21.95 | $21.95
3 | 1 | Bone Conduction Headphones | $17.88 | $17.88
4 | 1 | DC Coreless Vibration Motor | $8.99 | $8.99
5 | 2 | Arducam 1080P USB Camera | $34.99 | $69.98
6 | 1 | 100 count 5mm x 5mm LED Lights | $4.99 | $4.99
7 | 1 | Braided Nylon Watch Band | $11.99 | $11.99
8 | 1 | 10 Count 10k Ohm Photoresistor | $7.90 | $7.90
9 | 1 | 100 Count Push Buttons | $5.39 | $5.39
10 | 1 | Power Supply (5V, 4.5 A) | $26.98 | $26.98
11 | 1 | 3d Printing Filament | $3.00 | $3.00
12 | 1 | Fanny Pack Holster | $8.95 | $8.95
13 | 1 | Jumper Wires Pack | $2.00 | $2.00
Beta Version-Total Cost | | | | $349.99

The main expense for the beta version of the product is the Raspberry Pi 5 w/ 16 GB of RAM, accounting for over 45% of the total cost. The need for such a powerful device can be attributed to the need for quick onboard computer vision processing. However, there is still a need to make an external API call within the workflow. When scaling to production, it may make sense to downgrade the onboard hardware in favor of hosting an external cloud solution for processing.
All software and API calls used were free, open source, or provided free services with rate limiting. This limits the cost of the product to just the hardware components. In production, these costs will be further reduced due to the ability to buy in bulk.

User's Manual | 14

### 7 Appendices

### 7.1 Appendix A - Specifications

Core Components

- Dual 2MP Arducam 1080P Day/Night Vision USB Cameras (stereoscopic vision for depth mapping)
- TinyPico ESP32 Microcontroller Board
- Raspberry Pi 5 (16GB RAM)
- Bone Conduction Bluetooth Powered Headset (Bluetooth 5.3, open ear construction)
- Wrist-Wearable Module with:
- 7x25mm Micro Vibrating Motor (1–6V, 8000–20000 RPM)
- 2x 5x5mm White LED Diodes (6000K)
- 6x6mm White Push Button
- LDR Photoresistor (10kΩ)
- INIU Portable Charger (10000 mAh)
- Router (for WiFi communication)

Battery Life

- Bone conduction Bluetooth headset: 6–10 hours of use per charge, 2-hour charging time1
- Raspberry Pi and TinyPico: 10 hours battery life estimated

Connectivity

- Bluetooth 5.3 (headset)
- WiFi (UDP communication between ESP32 and Raspberry Pi 5)
- Potential for LTE connectivity in future iterations

Performance

- Wrist-Wearable to Smart Cap signal transmission: ≥95% success rate
- Dual-camera snapshot initiation: <5 seconds from signal
- Depth mapping image processing: <1 second
- Haptic feedback system: immediate response upon signal receipt
- Speech engine response accuracy: 85–90% in quiet environments
- Intelligent Visibility System (LEDs in low light): >75% activation rate

User Interaction

- Wrist-wearable button triggers image capture and analysis
- Auditory feedback via bone conduction headset
- Haptic alerts for immediate obstacles
Team 29 (Smart Bears) | April 18, 2025

Physical Dimensions

- Micro vibrating motor: 7x25mm
- LED diodes: 5x5mm
- Push button: 6x6mm
- Cameras: Standard USB 2MP module size 32x32mm each
- Wrist-wearable: Adjustable strap (unisex expandable strap)

Expandability

- Future LTE upgrade possible for Raspberry Pi 5 to remove WiFi dependency

### 7.2 Appendix B – Team Information

Smart Bears is a dynamic team of five computer engineers—Lukas Chin, Jake T. Lee, Shamir Legaspi, David Li, and Jason Li—who first connected during their freshman year at Boston University. Their shared passion for technology and innovation quickly brought them together, leading to collaborations on a variety of personal and group projects throughout their undergraduate journey. Each member brought unique interests within computer engineering, ranging from mobile and cloud computing to artificial intelligence, data science, and hardware systems. This diversity of expertise enabled them to approach problems from multiple perspectives and develop creative, robust solutions.

Throughout their time at BU, the Smart Bears immersed themselves in a rigorous curriculum that combined foundational engineering theory with hands-on technical experience. The Department of Electrical & Computer Engineering emphasized both individual and teamwork skill-building, exposing students to real-world challenges and fostering a culture of interdisciplinary research and innovation. The team participated in research labs, internships, and university-sponsored competitions, further sharpening their technical and communication skills.

The culmination of their undergraduate experience was the Senior Design Capstone, where they leveraged everything they had learned to design and prototype an ambitious, innovative product. This project required them to collaborate closely, navigating technical challenges, managing project timelines, and engaging with real-world clients—experiences that mirrored professional engineering environments and solidified their teamwork. Their collective efforts not only showcased their technical acumen but also highlighted their ability to translate classroom knowledge into impactful engineering solutions.

Following graduation, Lukas will be continuing work on his mobile app startup. Jake will be working at a startup. Shamir will be working at an AI-based startup. David will be working at a chip-based startup. Jason Li will be working at Deloitte as a consultant.

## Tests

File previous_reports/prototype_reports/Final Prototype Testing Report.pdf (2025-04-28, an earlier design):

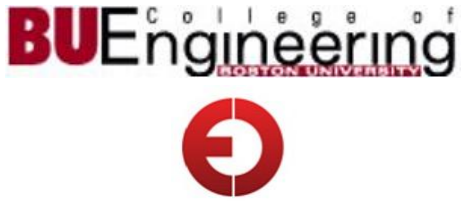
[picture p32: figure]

# Boston University Electrical & Computer Engineering

EC464 Senior Design Project

# Final Testing Plan Smart System for Visually Impaired


by

Team 29
Smart Bears

Team Members

Lukas Chin | lchin10@bu.edu
Jake Lee | jaketlee@bu.edu
Shamir Legaspi | slegaspi@bu.edu
Jason Li | jli3469@bu.edu
David Li | dav@bu.edu

Required Materials For Prototype Demonstration

Hardware Related:

- 7x25mm Micro Vibrating Motor (1-6V) (8000-20000 RPM)
- 2x 5x5mm LED Diode Lights White (6000K)
- 6x6mm White Push Button
- LDR Photoresistor (10k ohms)
- TinyPico ESP32 Microcontroller Board
- 2x Arducam 1080P Day/Night Vision USB Camera, 2MP
- Raspberry Pi 5 (16GB)
- Bone Conduction Bluetooth Powered Headset
- Router
- INIU Portable Charger (0000 mAh)

Software Related:

- Python Script(s):
- Photo Snapshot Program
- Depth Mapping

■ OpenCV

■ Stereo Block Matching

- Object Inquiry Assistant (Large Language Model)

■ Feeds outputs of depth mapping to LLM to provide feedback.

- UDP communication

■ Two-way communication with ESP32 and Raspberry Pi 5 over WiFi

- Wrist-Wearable Signal Handling GPIO
- Wrist-Wearable Intelligent Visibility System

Set Up

Our final prototype involves a successful demonstration of the Smart System, a unity of the Smart Cap and the Wrist-Wearable. The core feature of our Smart System is its OIA (Object Inquiry Assistant) which feeds the output of the stereoscopic depth mapping to provide useful feedback to the user. OIA processes user queries through an image-based large language model for comprehensive environmental surrounding analysis.

The smart system utilizes two separate 2MP cameras to create accurate depth maps, which are essential for spatial awareness. The depth mapping generates a heatmap image where color gradients represent the relative distances of objects from the camera at the time of the snapshot. This stereoscopic vision technique simulates human binocular vision, effectively restoring depth perception to help visually impaired users avoid obstacles more efficiently.

Users interact with the inquiry system by pressing the button on the Wrist-Wearable to prompt the OIA to take a snapshot in front of them. This triggers the system to analyze and process the images and relay a message to the user. The message is sent through our Live Speech Engine where the user can hear the message through the bone conduction headphones via Bluetooth. It will also send a signal back to the Wrist-Wearable to trigger our Smart Vibration System. If there is an immediate obstacle detected, the vibrations will be more violent to alarm the user of the possible danger near them.

When the visual system captures the forward-facing environment through both cameras, it processes the images through our various implemented algorithms. The object detection model identifies and classifies objects in real time, highlighting them in bounding boxes. Depth mapping is powered by an OpenCV Python program where we’ve implemented a robust stereo block matching algorithm; the depth mapping image shows a heatmap image where the gradient of the colors represent how far objects are from the user at the time of snapshot.. These processed images along with a finely tuned system prompt are then passed to an LLM via an API over WiFi, providing the user with a detailed response about their surroundings.

The Bluetooth powered headset features an estimated battery life of 6-10 hours with a 2-hour charging time, utilizing Bluetooth 5.3 with open ear construction to maximize comfort and reduce overstimulation.

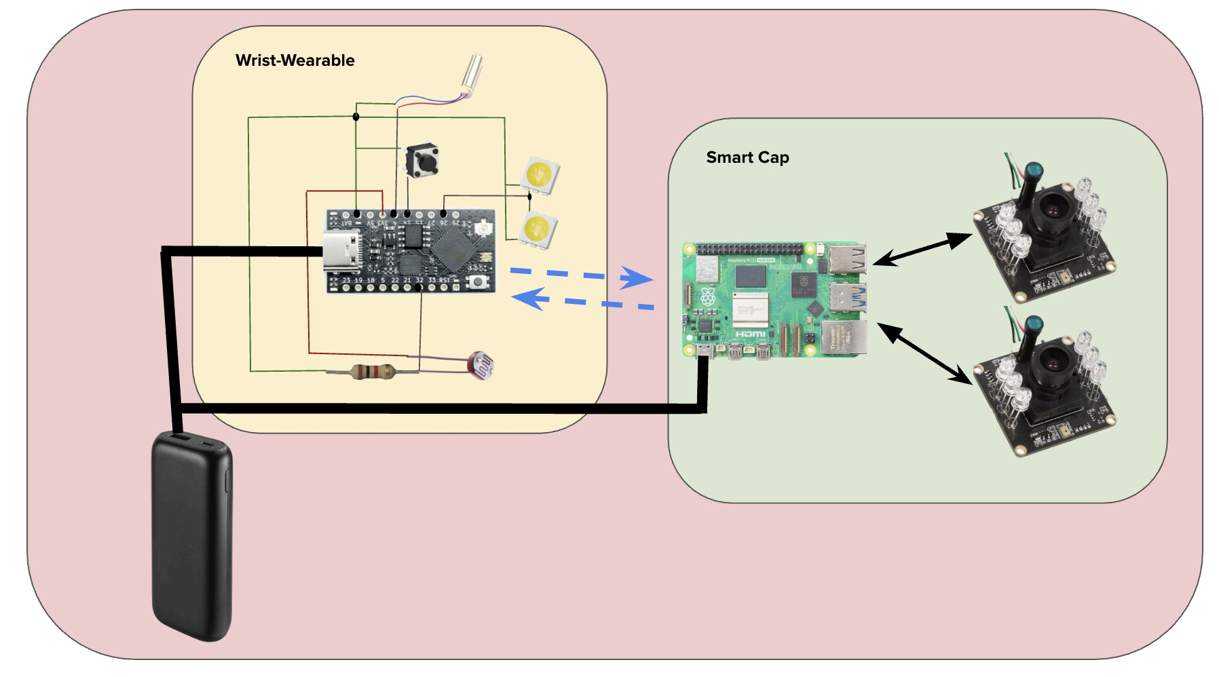
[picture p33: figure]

Figure 1. Final Prototype Smart Cap and Write Wearable Block Diagram

Pre-Testing Setup Procedure:
1. Ensure Wrist-Wearable and Smart Cap are powered on and functioning properly with both webcams appropriately attached.
2. Adjust the strap on the Wrist-Wearable for the user’s wrist.
3. Calibrate the depth mapping for the 2 webcams through our Python script.
4. Set up the Bluetooth powered headset by pairing to the Smart Cap and ensuring connectivity to the device running speech engine.
Testing Procedure
To test Smart System:
1. Point cameras in direction of interest and press the white button on the center of the Wrist-Wearable device. Pressing the button again before a response is received from the Pi should do nothing.
2. Both webcams of the Pi should capture images.
3. The depth mapping of the images is processed on the Pi.
4. The original image and depth map are sent to Gemini through an API alongside a system prompt.
5. The response from Gemini is spoken through the bluetooth speakers.

6. The response is also parsed to pass a signal to the wrist wearable, causing a vibration signal to be sent.
To test Wrist-Wearable Intelligent Visibility System:
1. Place the photoresistor of the wrist wearable in a sufficiently dark area until the LEDs begin to light up and breathe.
2. Ensure that there is no feedback from the LEDs into the photoresistor so that the system will not flash between states.

Measurable Criteria
The criteria that indicate success are as follows:
I. The Wrist-Wearable should send a signal to the Smart Cap through a UDP socket with at least 95% success rate.
II. | The Wrist-Wearable should wait for a response from Smart Cap before initiating additional
| signals through the button press.
III. | Smart Cap visual workflow should indicate received signal from the Wrist-Wearable and begin
| taking a photo in less than 5 seconds with both cameras.
IV. | Smart Cap should process the photo with our depth mapping algorithm in less than 1 second.
V. Processed output should be sent back to the Wrist-Wearable through a UDP socket where
| Wrist-Wearable engages its Smart Vibration Motors .
VI. | Bluetooth headset begins its Live Speech Engine after output from Smart Cap is processed at 90%
| accuracy.
VII. | The Intelligent Visibility System in Wrist-Wearable responds to dark conditions at least 75% of
| the time.

Score Sheet

Tasks | Successful? (Y/N)
Wrist-Wearable successfully sends signal to Smart Cap | Y
Wrist-Wearable successfully waits for response from Smart Cap before trying to send another signal | Y
Smart Cap takes a photo in less than 5 seconds after receiving signal from Wrist-Wearable | Y
Smart Cap processes photo with depth mapping algorithm in < 1 second | Y
Processed output is successfully sent back to Wrist-Wearable where its Smart Vibration Motors are turned on | Y
Bluetooth headset is engaged and the Live Speech Engine successfully outputs an auditory response | Y
The Intelligent Visibility System on the Wrist-Wearable responds to dark environments >75% of the time | Y
Result → | 100% Successful!

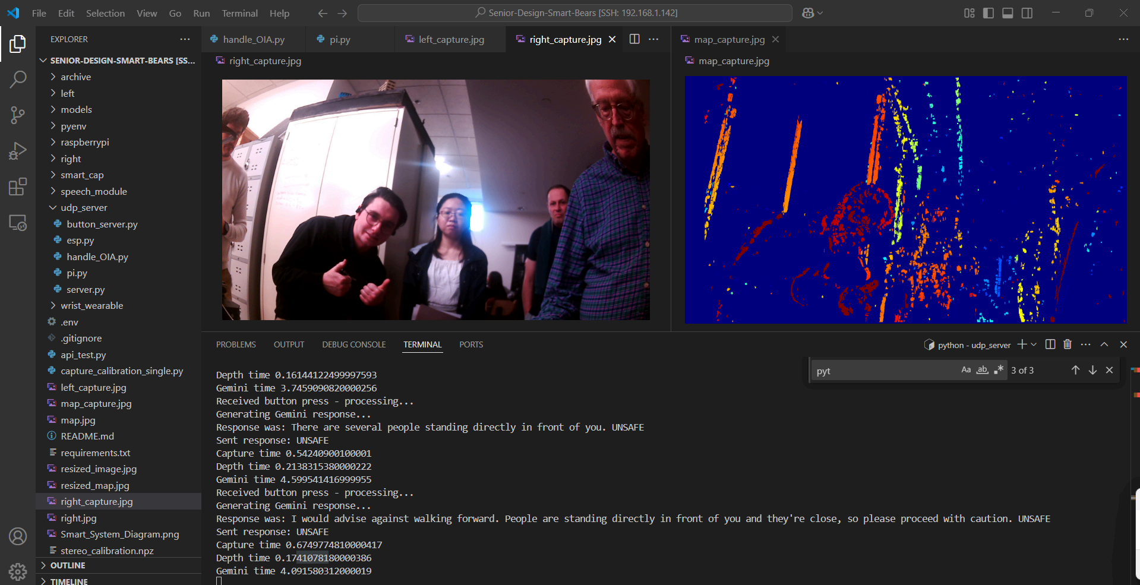
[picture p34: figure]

Prototype Results
The Smart System for Visually Impaired achieved 100% success across all primary evaluation criteria outlined in the testing plan. The Wrist-Wearable reliably communicated with the Smart Cap via UDP sockets, triggering dual-camera snapshots within <5 seconds and processing depth maps using OpenCV’s stereo block matching algorithm in <1 second. The haptic feedback system in the Wrist-Wearable activated successfully upon receiving processed signals from the Smart Cap, while the Bluetooth bone conduction headset delivered auditory responses at 85% accuracy in quiet environments. The Intelligent Visibility System also exceeded expectations, responding to low-light conditions >75% of the time by activating LED breathing patterns. Our hardware integration proved robust, with the Raspberry Pi 5 managing simultaneous tasks including stereoscopic imaging and API communication with Gemini without crashes or connectivity drops.
All foundational systems including stereoscopic depth mapping, vibration alerts, and live speech synthesis operated within specifications. The possible introduction of an LTE chip on the RaspberryPi can remove the dependence on a local WiFi network. For future iterations, this will greatly increase the mobility of the product and only require changes to configuration files.

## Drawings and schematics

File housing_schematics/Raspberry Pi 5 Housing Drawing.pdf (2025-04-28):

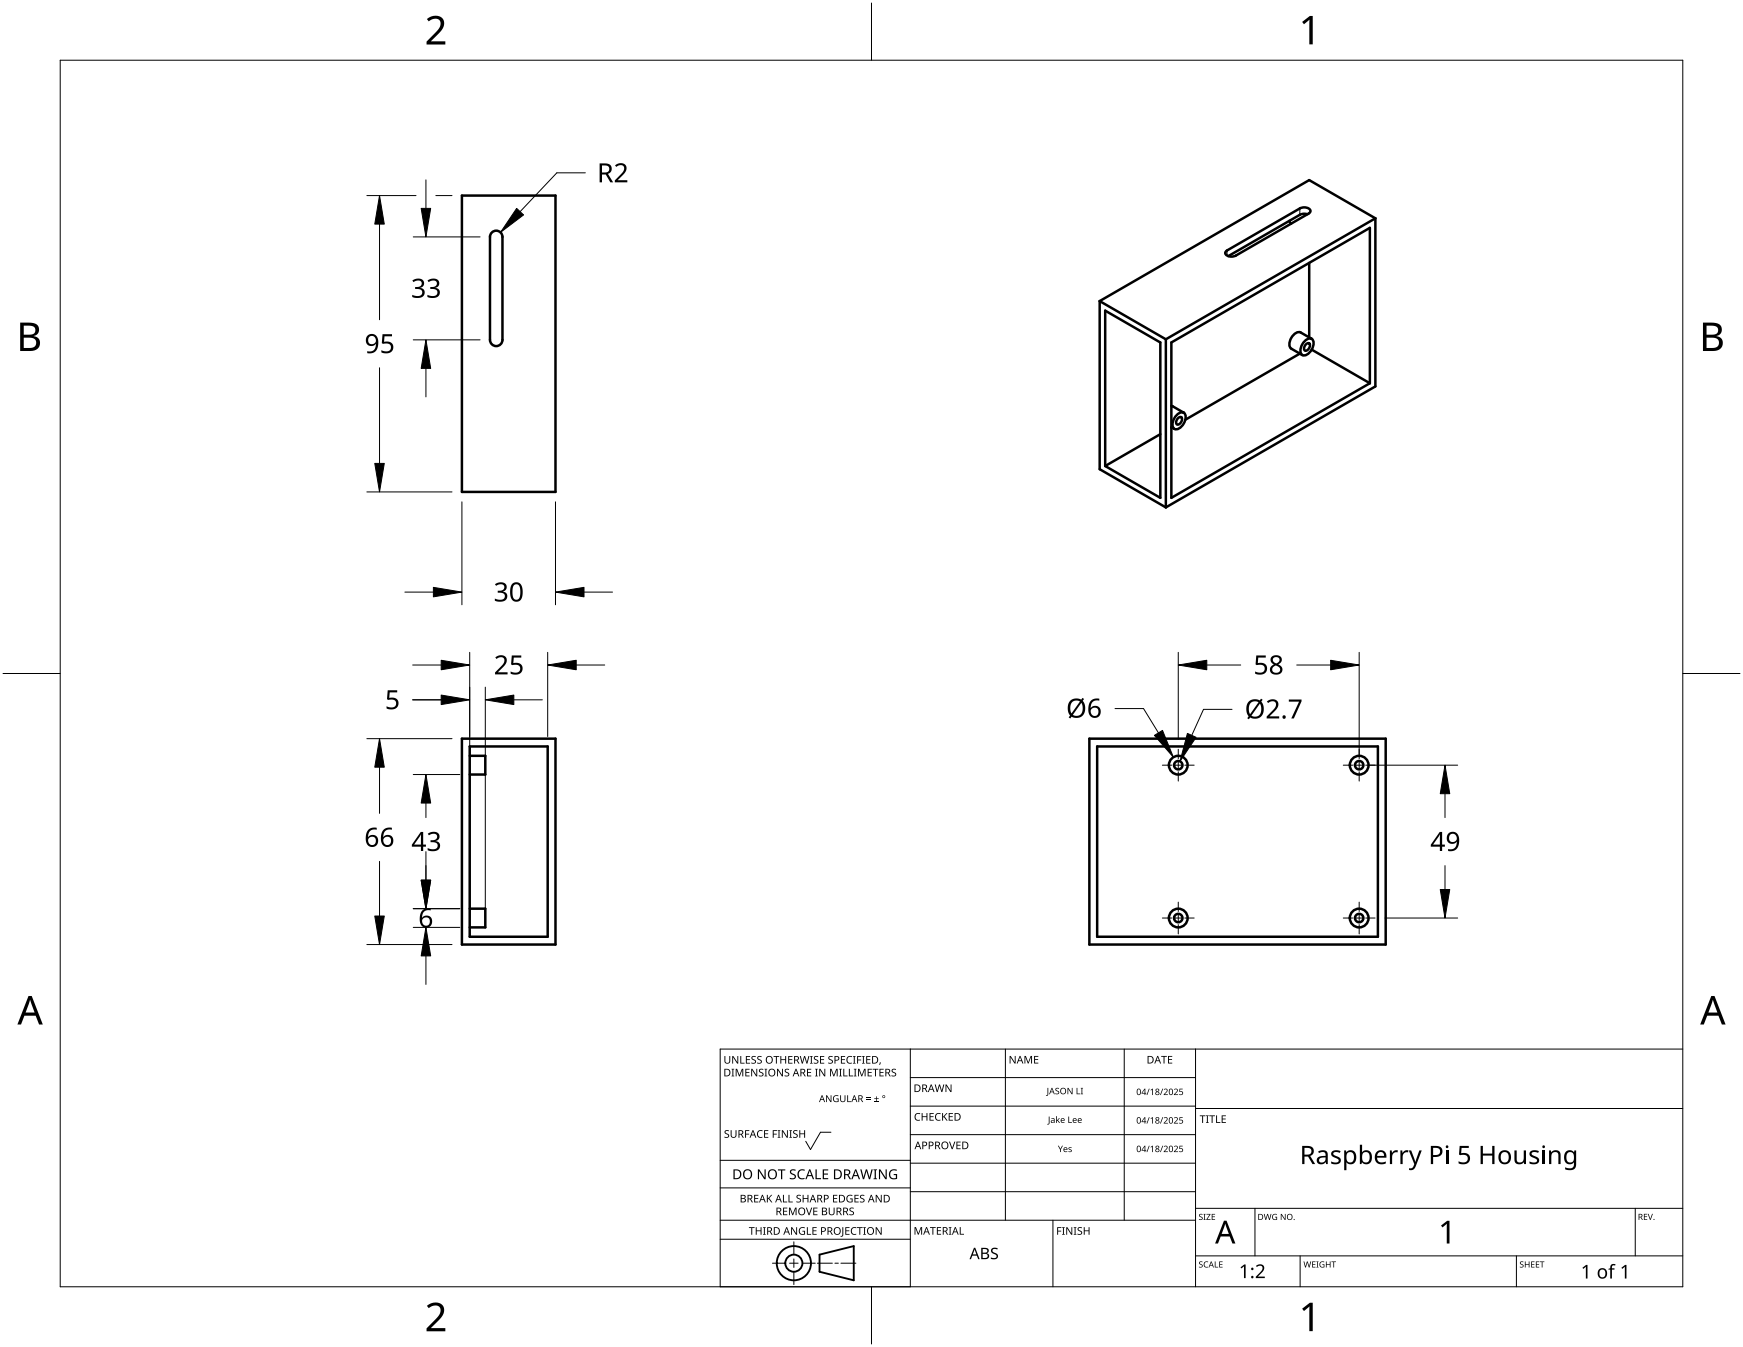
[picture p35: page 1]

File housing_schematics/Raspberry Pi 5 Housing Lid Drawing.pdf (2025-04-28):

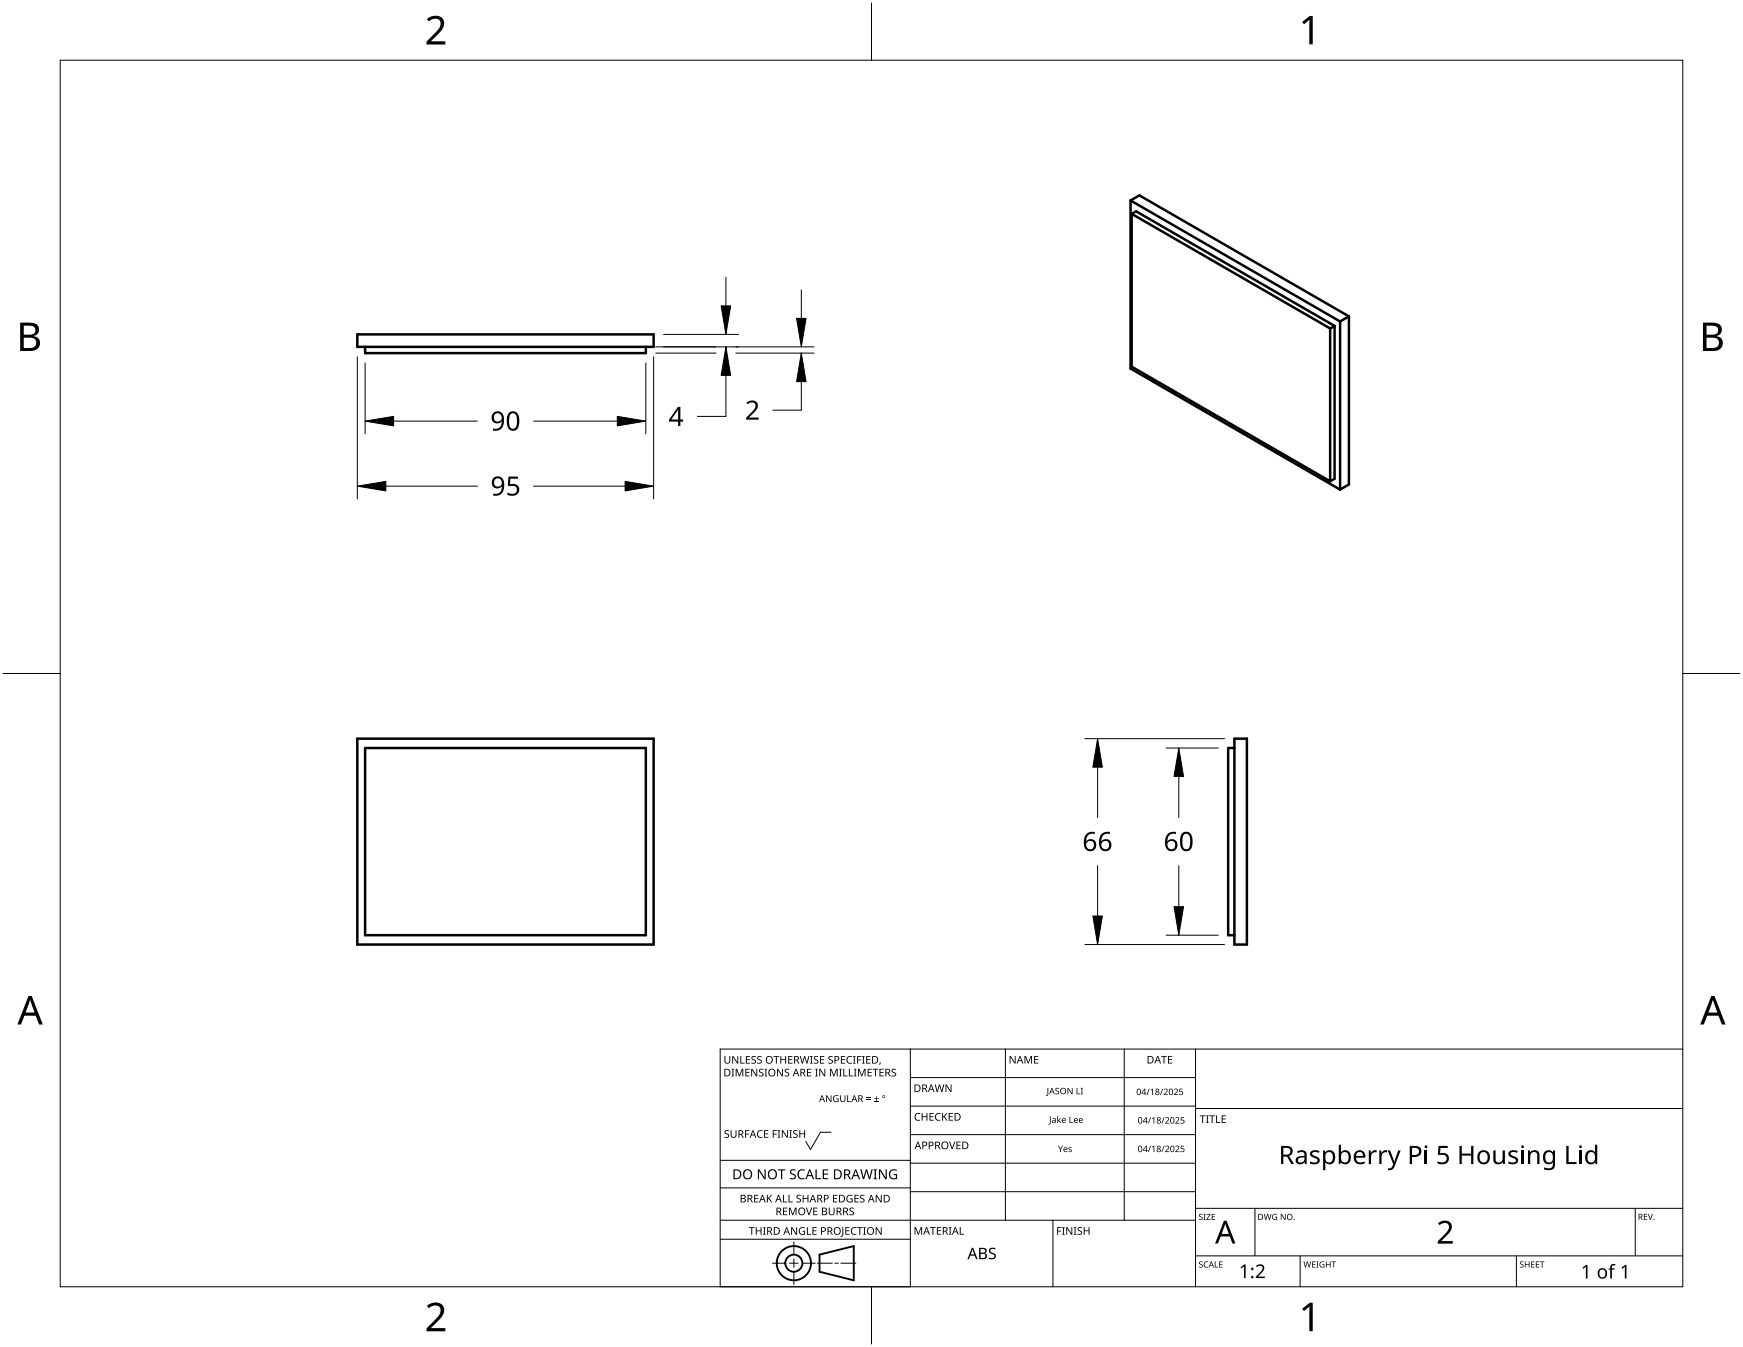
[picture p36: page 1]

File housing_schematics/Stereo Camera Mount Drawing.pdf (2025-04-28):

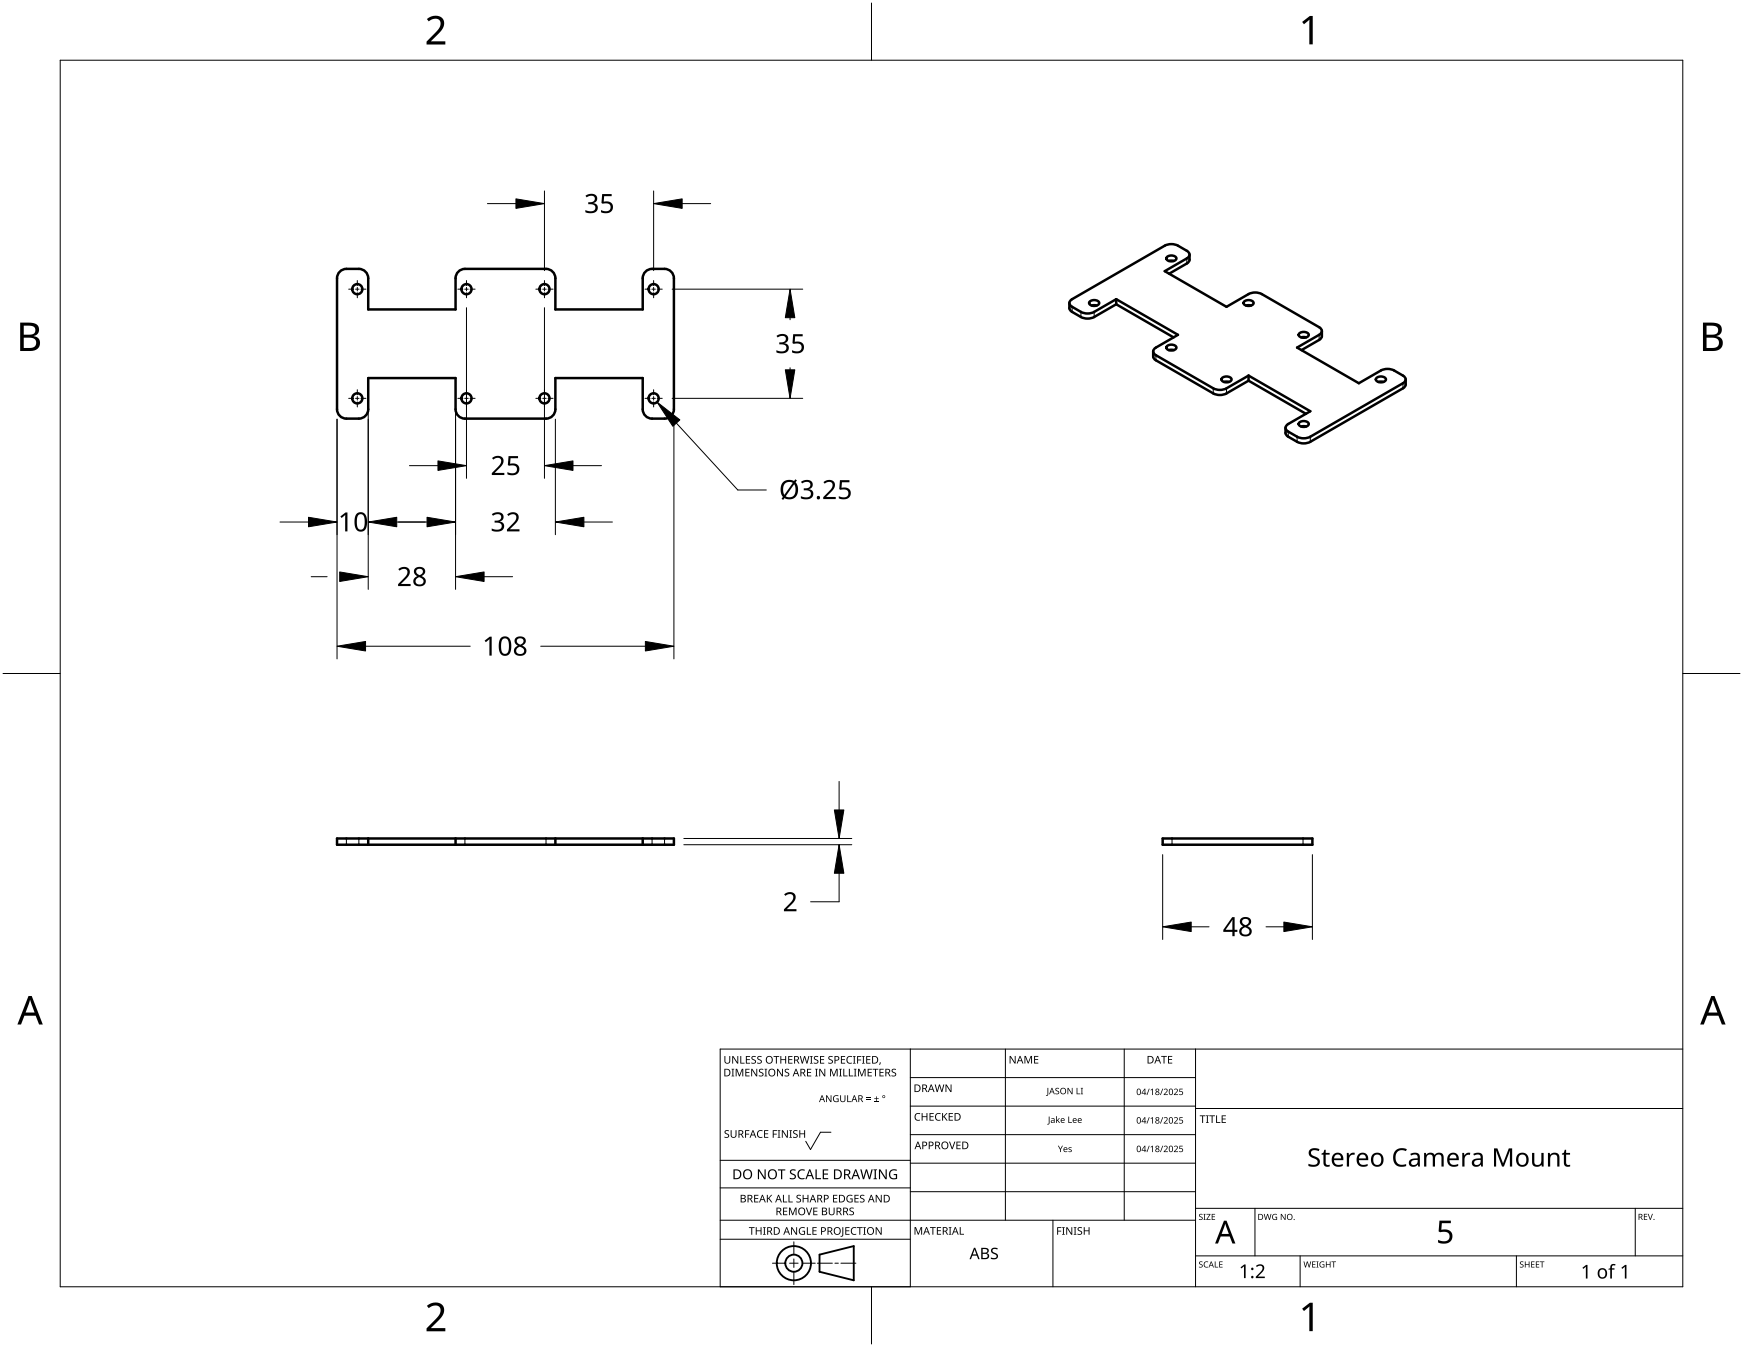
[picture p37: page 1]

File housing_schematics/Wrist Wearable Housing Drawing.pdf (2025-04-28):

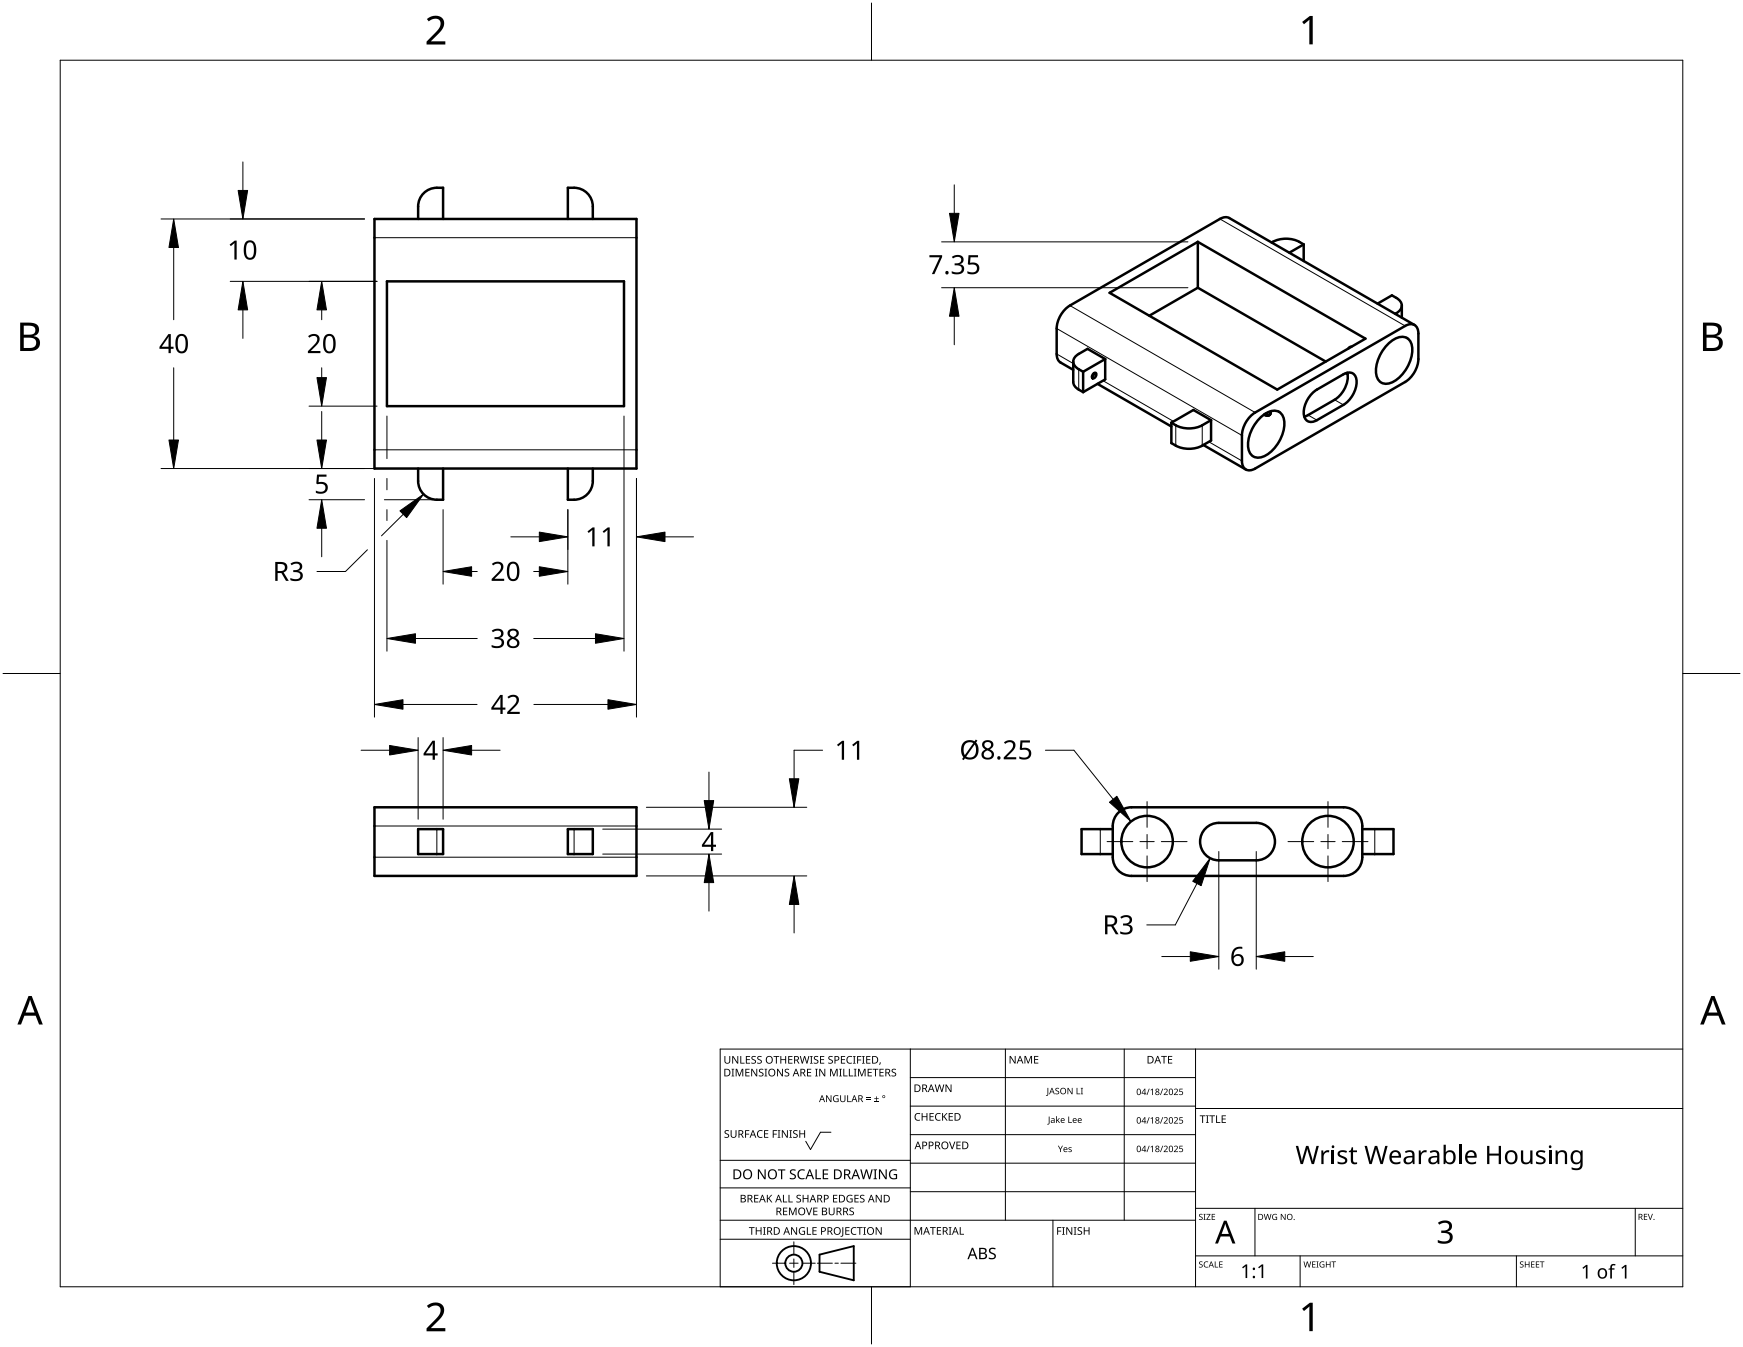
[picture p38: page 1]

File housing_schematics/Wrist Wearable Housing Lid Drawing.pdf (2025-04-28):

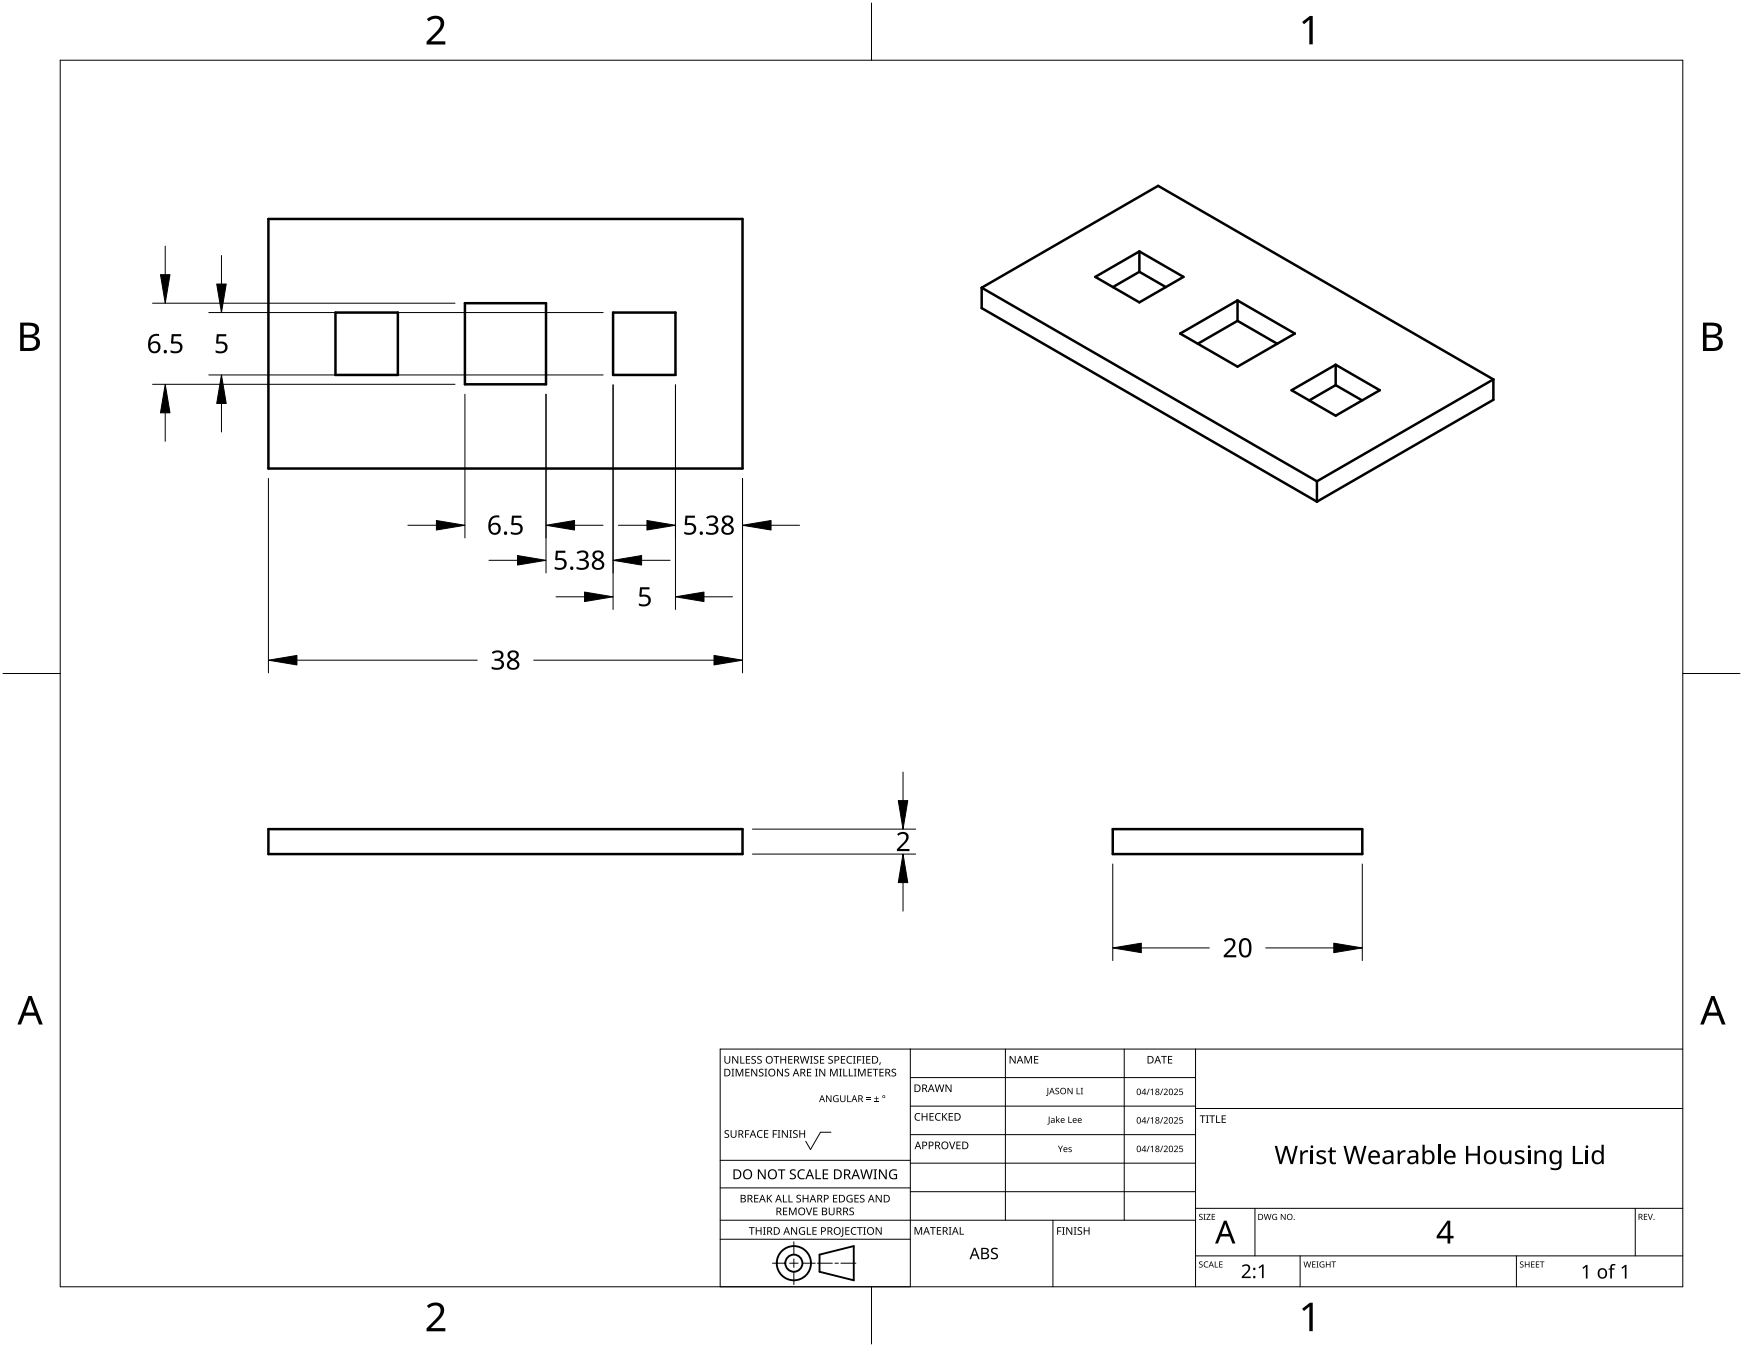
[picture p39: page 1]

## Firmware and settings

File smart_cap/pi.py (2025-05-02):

import socket
import time
import subprocess
import cv2
import pyttsx3
import sys
import numpy as np
import google.generativeai as genai
from dotenv import load_dotenv
import os
from PIL import Image

# UDP Setup
UDP_IP = ''
UDP_PORT = 12345

sock = socket.socket(socket.AF_INET, socket.SOCK_DGRAM)
sock.bind((UDP_IP, UDP_PORT))

print(f"Listening on port {UDP_PORT}")

# Initialize video captures
print("Initializing video captures")
cap_left = cv2.VideoCapture(0)  # Adjust index if needed
cap_right = cv2.VideoCapture(2)  # Adjust index if needed

# Set resolution for both cameras
width, height = 1920, 1080
cap_left.set(cv2.CAP_PROP_FRAME_WIDTH, width)
cap_left.set(cv2.CAP_PROP_FRAME_HEIGHT, height)
cap_right.set(cv2.CAP_PROP_FRAME_WIDTH, width)
cap_right.set(cv2.CAP_PROP_FRAME_HEIGHT, height)
cap_left.set(cv2.CAP_PROP_BUFFERSIZE, 1)
cap_right.set(cv2.CAP_PROP_BUFFERSIZE, 1)

# Initialize stereo
# Load calibration data (you need to perform calibration beforehand)
calibration_data = np.load('/home/pi/Senior-Design-Smart-Bears/camera_calibration/predefined_stereo_calibration.npz')
camera_matrix_left = calibration_data['camera_matrix_left']
dist_coeffs_left = calibration_data['dist_coeffs_left']
camera_matrix_right = calibration_data['camera_matrix_right']
dist_coeffs_right = calibration_data['dist_coeffs_right']
R = calibration_data['R']
T = calibration_data['T']

# Compute rectification transforms
image_size = (1920, 1080)  # Adjust to your camera resolution
R1, R2, P1, P2, Q, _, _ = cv2.stereoRectify(camera_matrix_left, dist_coeffs_left,
                                            camera_matrix_right, dist_coeffs_right,
                                            image_size, R, T)

# Compute rectification maps
map1_left, map2_left = cv2.initUndistortRectifyMap(camera_matrix_left, dist_coeffs_left, R1, P1, image_size, cv2.CV_32FC1)
map1_right, map2_right = cv2.initUndistortRectifyMap(camera_matrix_right, dist_coeffs_right, R2, P2, image_size, cv2.CV_32FC1)

# Create StereoBM object
stereo = cv2.StereoBM_create(numDisparities=80, blockSize=15)
stereo.setSpeckleWindowSize(25)
stereo.setSpeckleRange(1)
stereo.setTextureThreshold(12)  

# Initializing speech engine
speaker = pyttsx3.init()
speaker.setProperty ('rate', 150)
# Initialize LLM connection
load_dotenv()
api_key = os.getenv("API_KEY")

# Initialize Gemini client
system_instruction="""
You are an AI assistant designed to help visually impaired users, referred to as 'Senior Design Smart Bears', navigate their environment safely and confidently.
You are always provided with:
1. A regular color image of the user's forward view.
2. A depth map image showing relative distances (red = close, blue = far).

First use the regular color image to identify objects and understand what is in the user's view.
Next, check if the depth map has useful information. If there is not enough information in the depth map or it is too noisy, disregard the depth mapping image when performing the following task.
Then, if you do identify objects and are able to make use of the depth mapping image, use the depth mapping outlines to understand the relative distances of the objects. 

Your job is to describe only what's important based on their question**for immediate awareness, visual assitance, or navigation**.
- Mention nearby obstacles or objects directly in front.
- Highlight potential hazards if necessary for the question (e.g. steps, vehicles, poles, moving objects).
- Use clear, brief, conversational language like you're a helpful guide walking next to them.
- Provide distance estimates for objects in your response.
Avoid long explanations or visual details that don't affect the user's path or safety.
Keep responses concise and focused on action and awareness.
Append the word SAFE to the end of your response if it is safe to continue walking. Append the word UNSAFE to the end of your response if it is not safe to continue walking. Only append one of the two words.
"""

genai.configure(api_key=api_key)
model = genai.GenerativeModel(model_name='gemini-2.0-flash', system_instruction=system_instruction)

print("Waiting for button press")
while True:
    data, addr = sock.recvfrom(1024)
    if data == b'BUTTON_PRESSED':
        print("Received button press - processing...")
        
        start_time = time.perf_counter()
        # Run handle_OIA.py and capture output
        # Capture frames
        cap_left.grab()
        cap_right.grab()
        ret_left, frame_left = cap_left.read()
        ret_right, frame_right = cap_right.read()

        cv2.imwrite("/home/pi/Senior-Design-Smart-Bears/left_capture.jpg", frame_left)
        cv2.imwrite("/home/pi/Senior-Design-Smart-Bears/right_capture.jpg", frame_right)

        finish_capture_time = time.perf_counter()

        left_rectified = cv2.remap(frame_left, map1_left, map2_left, cv2.INTER_LINEAR)
        right_rectified = cv2.remap(frame_right, map1_right, map2_right, cv2.INTER_LINEAR)

        # Convert to grayscale
        gray_left = cv2.cvtColor(left_rectified, cv2.COLOR_BGR2GRAY)
        gray_right = cv2.cvtColor(right_rectified, cv2.COLOR_BGR2GRAY)

        # Compute disparity map
        disparity = stereo.compute(gray_left, gray_right)
        
        # Normalize disparity for display
        disparity_normalized = cv2.normalize(disparity, None, alpha=0, beta=255, norm_type=cv2.NORM_MINMAX, dtype=cv2.CV_8U)
        
        # Apply color map for visualization
        disparity_color = cv2.applyColorMap(disparity_normalized, cv2.COLORMAP_JET)

        # Save disparity map
        cv2.imwrite("/home/pi/Senior-Design-Smart-Bears/map_capture.jpg", disparity_color)

        rgb_frame = cv2.cvtColor(frame_right, cv2.COLOR_BGR2RGB)
        rgb_map = cv2.cvtColor(disparity_color, cv2.COLOR_BGR2RGB)

        frame_PIL = Image.fromarray(rgb_frame)
        map_PIL = Image.fromarray(rgb_map)

        finish_depth_time = time.perf_counter()

        print("Generating Gemini response...")

        response = model.generate_content([frame_PIL, map_PIL, "Is it safe to walk forward?"])

        finish_gemini_time = time.perf_counter()

        response_text = response.text

        print(f"Response was: {response.text}")

        speaker.say("Beginning Speech." + response_text + "Ending speech")
        speaker.runAndWait()

        flag = response_text.split(" ")[-1]

        # Send result back to ESP
        sock.sendto(flag.encode(), (addr[0], 54321))
        print(f"Sent response: {flag}")

        print("Capture time", finish_capture_time - start_time)
        print("Depth time", finish_depth_time - finish_capture_time)
        print("Gemini time", finish_gemini_time - finish_depth_time)

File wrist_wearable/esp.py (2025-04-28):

from machine import ADC, Pin, PWM
import usocket as socket
import network
import time
import math

# ---------- Photoresistor/LED Configuration ----------
# Photoresistor setup
ldr = ADC(Pin(32))
ldr.atten(ADC.ATTN_11DB)
led = PWM(Pin(27))
led.freq(1000)

# Light thresholds
BRIGHT_THRESHOLD = 3000
DARK_THRESHOLD = 4000

# Gradient parameters
t = 0
LAST_GRADIENT_UPDATE = 0
GRADIENT_INTERVAL = 50  # Update every 50ms

# ---------- Button/Vibration Configuration ----------
# Hardware setup
BUTTON_PIN = 14
VIBRATOR_PIN = 4
button = Pin(BUTTON_PIN, Pin.IN, Pin.PULL_UP)
vibrator = PWM(Pin(VIBRATOR_PIN), freq=1000, duty=0)

# ---------- WiFi Configuration ----------
# WiFi credentials
WIFI_SSID = "smartbears"
WIFI_PASSWORD = ""

# Connect to WiFi
wlan = network.WLAN(network.STA_IF)
wlan.active(True)
if not wlan.isconnected():
    print("Connecting to WiFi...")
    wlan.connect(WIFI_SSID, WIFI_PASSWORD)
    while not wlan.isconnected():
        time.sleep(0.5)
print("Connected to WiFi:", wlan.ifconfig())

# Network config
SERVER_IP = "192.168.1.142"
SERVER_PORT = 12345
LOCAL_PORT = 54321

# State management
awaiting_response = False
LAST_BUTTON_CHECK = 0
BUTTON_INTERVAL = 50  # Check every 50ms

# UDP socket
udp_socket = socket.socket(socket.AF_INET, socket.SOCK_DGRAM)
udp_socket.bind(('0.0.0.0', LOCAL_PORT))
udp_socket.settimeout(0.01)

def update_gradient():
    global t, LAST_GRADIENT_UPDATE
    current_time = time.ticks_ms()
    
    if current_time - LAST_GRADIENT_UPDATE >= GRADIENT_INTERVAL:
        raw_value = ldr.read()
        
        if raw_value >= DARK_THRESHOLD:
            t += 0.3
            t %= (2 * 3.14)
            led_brightness = (math.sin(t) + 1) * 511
            led.duty(int(led_brightness))
        else:
            led.duty(0)
        
        LAST_GRADIENT_UPDATE = current_time

def handle_vibration(response):
    global awaiting_response
    
    if response == 'UNSAFE':
        # Three vibration bursts with pauses
        for i in range(2):
            vibrator.duty(512)  # Strong vibration
            time.sleep(1)
            vibrator.duty(0)    # Pause
            if i < 1:  # No pause after last iteration
                time.sleep(0.5)
                
    else:
        # Single vibration as before
        vibrator.duty(256)
        time.sleep(1)
        vibrator.duty(0)
    
    # Reset state after pattern completes
    awaiting_response = False

def check_button():
    global awaiting_response, LAST_BUTTON_CHECK
    current_time = time.ticks_ms()
    
    if current_time - LAST_BUTTON_CHECK >= BUTTON_INTERVAL:
        if button.value() == 0 and not awaiting_response:
            udp_socket.sendto(b'BUTTON_PRESSED', (SERVER_IP, SERVER_PORT))
            awaiting_response = True
            print("Button pressed - request sent")
        LAST_BUTTON_CHECK = current_time

def check_messages():
    try:
        data, addr = udp_socket.recvfrom(1024)
        if data and awaiting_response:
            print("Received:", data.decode())
            handle_vibration(data.decode())
    except:
        pass

# ---------- Main Loop ----------
while True:
    # Run both systems simultaneously
    update_gradient()    # Photoresistor/LED system
    check_button()       # Button handling
    check_messages()     # Network response handling

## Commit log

2024-11-20 testing low latency camera stream
2024-11-20 added venv
    [pyvenv.cfg]
2024-11-20 improve camera latency
2024-11-21 lidar code
2024-11-21 camera rotation
2024-11-21 removed unecessary files
    [pyvenv.cfg]
2025-02-05 whisper-stream prototype1
2025-02-19 calibration script
2025-02-19 capture script for calibration
2025-02-27 calibration on computer
2025-04-01 button press wrist wearable functionality
2025-04-02 adding led python script
2025-04-03 pin number
2025-04-03 new calibration
2025-04-03 changed led pin
2025-04-27 reports added + cad folder
2025-04-27 upload CAD drawings
2025-04-27 upload raw CAD files
    [RaspberryPi5Housing.stl, RaspberryPi5HousingLid.stl, StereoCamMountV2.stl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]
2025-04-28 changed names
    [RaspberryPi5Housing.stl, RaspberryPi5HousingLid.stl, StereoCamMountV2.stl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]
